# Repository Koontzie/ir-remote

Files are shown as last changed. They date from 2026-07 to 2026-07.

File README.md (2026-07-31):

# IR-Remote

**A three-button universal IR remote you program from your phone** — an ESP32-S3
blasts the infrared code, and a web page (no app store, no build step) tells it
which code to blast over Bluetooth.

<p align="center">
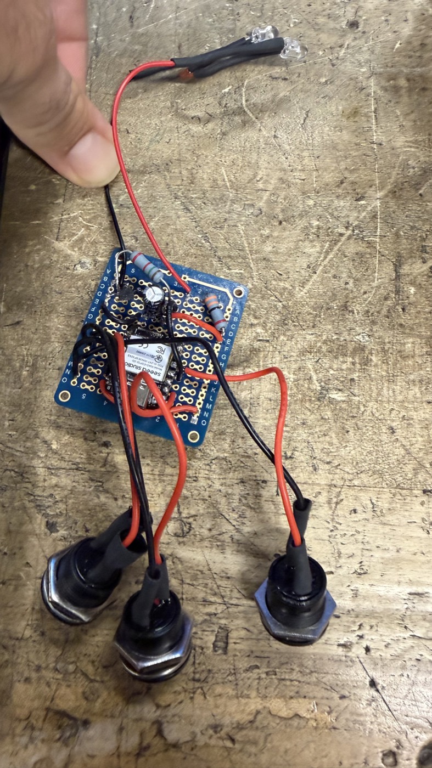
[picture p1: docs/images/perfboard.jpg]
The perf-board build: an ESP32-S3 on protoboard with a transistor IR driver, two IR LEDs on a flying lead, and three panel-mount arcade buttons.
  
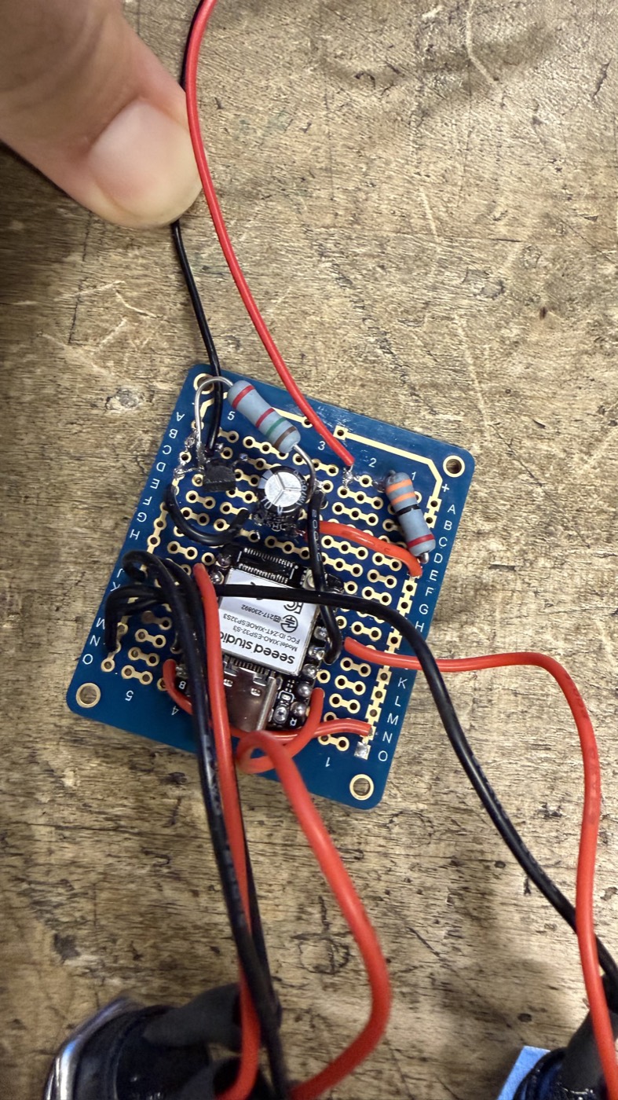
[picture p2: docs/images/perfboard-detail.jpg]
Close-up of the board: Seeed XIAO ESP32-S3, 2N2222 driver, 33-ohm and 1k resistors, and a 470uF bulk cap across the rails.
  
</p>

The point is the last-mile problem in AV work: you're standing in front of an
unlabelled projector or a hotel TV with no remote, and you need power and input
switching *now*. This is a Flipper Zero's universal-remote trick, on $10 of parts,
in a form factor with real buttons you can hit without looking.

## Try it

**→ [koontzie.github.io/ir-remote/app/](https://koontzie.github.io/ir-remote/app/)**

The app is a single static HTML file with no dependencies and no backend. It talks
to the board with **Web Bluetooth**, which means:

- **Desktop Chrome / Edge / Android Chrome** — works as-is.
- **iOS: you need [Bluefy](https://apps.apple.com/us/app/bluefy-web-ble-browser/id1492822055).**
  Not a preference — **Safari has no Web Bluetooth support at all**, and every iOS
  browser is Safari underneath except the handful that ship their own BLE bridge.
  Bluefy is one of those. Open the link above inside Bluefy.
- **Firefox** — no Web Bluetooth. Won't work.

Without hardware you can still browse the code library; the connect button is the
only thing that needs a board.

## How it works

```
[phone or laptop browser]  ──Web Bluetooth──▶  [ESP32-S3 · BLE GATT]
                                                     │  writes to NVS (flash)
[3 physical buttons] ──GPIO──▶ [firmware] ──▶ [2N2222 ──▶ 2× IR LED] ──▶ device
```

Assign a code to a slot once, and the board **keeps it through a power cycle and
fires it with the browser completely disconnected.** It's a real remote, not a
Bluetooth accessory — the phone is a programming tool, not a dependency.

The code library ships in the repo: **317 brands, ~11,100 codes** across TVs,
projectors, monitors, AV receivers, soundbars, cable boxes, Blu-ray and DVD.
Search a brand, pick a function, assign it to a button. Codes shared across many
models of a brand are flagged as "blanket" codes and floated to the top, because
those are the ones most likely to just work.

**GATT interface** (device name `IR-Remote`):

| Role | UUID | Payload |
|---|---|---|
| service | `b457c32b-22b1-425f-8a88-4d6dc37ba4eb` | — |
| `config` (write) | `d997012d-7d2b-47de-ae87-bae14df446ef` | `{"slot":1,"proto":"SAMSUNG","code":"0xE0E040BF","bits":32}` |
| `trigger` (write) | `58397514-04a3-4265-9590-9d910c4e99d2` | `{"slot":1}` |
| `status` (notify) | `b8ddfe01-519f-430d-bd4e-aba0dd852e2c` | `saved:N` / `sent:N` / `pressed:N` / `err:…` |

Five slots (1–5); protocols NEC, SAMSUNG, SONY.

⚠️ **The GATT server is unauthenticated** — anyone in Bluetooth range can write a
config or trigger a slot. That's fine for bench use and it's a deliberate
trade-off, not an oversight; NimBLE bonding would close it if this ever left the
workbench.

## Where it stands

**It works.** The core is built and proven on the bench: IR transmit across a room
(20–30 ft), programming over Bluetooth from the app, codes persisting in flash
through a power cycle, all three physical buttons, and the searchable code library
end to end — pick a Samsung power code in the browser, assign it to a button, and
the TV across the room turns off.

It's a finished thing that does its job. What follows is the honest edge of it,
not a to-do list I'm apologising for.

- **USB-powered.** The circuit runs off the dev board's 5 V pin, so it needs a
  cable or a USB battery pack. A battery-and-deep-sleep version was started and
  stopped after it cost a dev board — see the postmortem below.
- **Identify mode is written but unproven.** Sweeping power codes until the device
  reacts, plus favourites, is implemented in the app and firmware but has never
  been run against real hardware.
- **The custom PCB is designed, not fabricated.** `hardware/` has a complete
  KiCad project, placed and partly routed. Nothing has been sent to a fab, so
  nothing about it is proven.
- **Bluetooth link drops occasionally** (`reason 520`, supervision timeout).
  Annoying, not dangerous — the stored codes and the IR output were verified
  correct either side of every drop.

The unit in the photos is currently dead, and it's a good story rather than a sad
one: during the battery experiment a cheap boost converter's solder-blob voltage
selector let go, silently jumped to 9 V, and cooked the dev board's regulator. The
design was never at fault, a socketed dev board makes it a two-minute swap, and
the full postmortem — along with every other fault this project hit — is in
[docs/DEVLOG.md](docs/DEVLOG.md).

## What's next

No timeline and no promises — the project does what it was built to do. If I pick
it back up:

- **An enclosure.** It's loose boards and panel-mount buttons right now. This is
  the one thing that would turn it from a working circuit into something you'd
  actually carry to a job.
- **Prove out identify mode** on a fresh dev board — the sweep is the feature that
  makes it genuinely universal rather than a nice code browser.
- **Polish the app UI.** It's functional and fast, but it's plainly a tool built
  by one person for one person.

## Bill of materials

| Qty | Part | Notes |
|---|---|---|
| 1 | **Seeed Studio XIAO ESP32-S3** dev board | Any ESP32-S3 dev board works; this is what's pictured. **Socket it** — dev boards die, and a socket makes that a pull instead of a desolder. |
| 2 | IR LED, 940 nm | Wired in series. Salvaged from a dead remote here. Verify a salvaged emitter is actually IR — it glows violet-white on a phone camera. |
| 1 | 2N2222 NPN transistor, TO-92 | Any general-purpose NPN with ≥150 mA collector current. |
| 1 | 33 Ω resistor | LED current limit — sets the ~100 mA pulse. |
| 1 | 1 kΩ resistor | Transistor base. |
| 1 | 470 µF electrolytic capacitor | Bulk decoupling across the 5 V rail. Steadies the rail during LED pulses. |
| 3 | R13-507 16 mm momentary buttons | Panel-mount, solder lugs, no polarity. Any momentary SPST works. |
| 1 | Protoboard + hookup wire | |

Roughly $10–15 if you're buying everything, less if you're raiding a parts bin.

## Wiring

Full card with health checks and measured values: **[hardware/WIRING.md](hardware/WIRING.md)**.

```
POWER
  Dev board 5V pin ──► 5V rail
  Dev board GND    ──► GND rail
  470µF cap across the rails: (+) → 5V, (−) stripe → GND, near the driver.

IR DRIVER (2N2222, TO-92)
  5V rail ──33Ω──► LED1 anode(+)
  LED1(−) ──► LED2(+)                 [series pair, both 940nm]
  LED2(−) ──► COLLECTOR
  EMITTER ──► GND rail
  GPIO4 ──1kΩ──► BASE (middle leg)

BUTTONS (INPUT_PULLUP, pressed = LOW)
  GPIO5 ──► button ──► GND   → slot 1
  GPIO2 ──► button ──► GND   → slot 2
  GPIO7 ──► button ──► GND   → slot 3
```

Two things that cost real bench time here, so they're worth repeating:

- **Meter the transistor's legs; don't assume them.** E/C order varies by vendor
  for the same part number. In diode mode with the red probe on Base, the outer
  leg with the *higher* forward drop is the Emitter.
- **A resistor being present on the board is not the same as it being in the
  current path.** The 33 Ω must be in series with the LEDs, not in the cap's
  branch. Check continuity to the right *node*.

## Build and flash

Toolchain (macOS, Homebrew) — these exact versions are what's verified:

| | Version |
|---|---|
| `arduino-cli` | 1.5.1 |
| `esp32` core | 3.3.10 |
| IRremoteESP8266 | 2.9.0 |
| NimBLE-Arduino | 2.5.0 |
| ArduinoJson | 7.4.3 |

```sh
arduino-cli core install esp32:esp32
arduino-cli lib install IRremoteESP8266 NimBLE-Arduino ArduinoJson

arduino-cli board list      # the port number is NOT stable across replugs
arduino-cli compile --fqbn esp32:esp32:esp32s3:CDCOnBoot=cdc firmware/remote_ble
arduino-cli upload -p <PORT> --fqbn esp32:esp32:esp32s3:CDCOnBoot=cdc firmware/remote_ble

sleep 20 | arduino-cli monitor -p <PORT> -c baudrate=115200
```

`CDCOnBoot=cdc` is required — the S3 talks over native USB CDC, and serial stays
silent without it. `arduino-cli monitor` exits instantly if stdin is closed, hence
the `sleep 20 |` when scripting it.

`firmware/phase1_ir_test/` is a deliberately minimal known-good IR sketch — it
sends one hard-coded Samsung code every 3 seconds. When something stops working,
flash that first to prove the LED path before suspecting anything else.

### Running the app locally

```sh
cd app && python3 -m http.server 8000
```

Open `http://localhost:8000` in desktop Chrome. `localhost` counts as a secure
context, so Web Bluetooth works without HTTPS.

## Repository layout

| Path | What |
|---|---|
| `firmware/remote_ble/` | The real firmware — BLE GATT + IR + 5 NVS-backed slots |
| `firmware/phase1_ir_test/` | Minimal known-good IR sketch, kept as a bisect tool |
| `app/index.html` | The whole app. One file, vanilla JS, no build step |
| `data/` | Generated IR code database — see [data/README.md](data/README.md) |
| `tools/flipper_ir_convert.py` | Flipper `.ir` → IRremoteESP8266 JSON converter + scraper |
| `hardware/` | KiCad 10 PCB project (unfabricated) + the wiring card |
| `docs/` | Design docs and the development log |
| `PLAN.md` | The plan |
| `docs/DEVLOG.md` | A running log of what actually happened — including the failures, in detail |

### Docs

[Code library + Identify mode design](docs/DESIGN-code-library.md) ·
[PCB design](hardware/DESIGN-pcb.md) ·
[hardware working notes](hardware/README.md) ·
[the IR database](data/README.md)

`docs/DEVLOG.md` is worth a look if you're building one of these. It's a blow-by-blow
of every fault hit along the way and how each was actually diagnosed — a dev board
bricked by a boost converter that silently drifted to 9 V, a transistor installed
E/C-reversed, a BLE advertisement overflowing 31 bytes so the device name was
silently dropped, and a board stuck in ROM download mode that looked exactly like
dead firmware. Each entry ends with the lesson rather than just the fix.

## Credits / data sources

The IR code database is built from
**[Lucaslhm/Flipper-IRDB](https://github.com/Lucaslhm/Flipper-IRDB)**, released
under **[CC0-1.0](https://creativecommons.org/publicdomain/zero/1.0/)** — a public
domain dedication that asks nothing of anyone reusing it. It's credited here
anyway, because a community-maintained database of 300+ brands is a real piece of
work and saying so is good manners. See [data/README.md](data/README.md) for how
it's converted and regenerated.

The firmware stands on
[IRremoteESP8266](https://github.com/crankyoldgit/IRremoteESP8266) (despite the
name, first-class ESP32 support) and
[NimBLE-Arduino](https://github.com/h2zero/NimBLE-Arduino).

> **A note on history:** until 2026-07-31 this repo also contained two universal
> code lists taken from
> [DarkFlippers/unleashed-firmware](https://github.com/DarkFlippers/unleashed-firmware),
> which is **GPL-3.0**. Those files and everything derived from them were removed
> when the project adopted the MIT license, and the sweep lists were rebuilt from
> the CC0 database instead. **They are still present in earlier commits** — git
> history was not rewritten. Nothing in the current tree derives from them.

## License

[MIT](LICENSE) © 2026 Tyler Koontz.

## Support

If you found this useful, you can [buy me a coffee](https://ko-fi.com/tylerxkoontz).

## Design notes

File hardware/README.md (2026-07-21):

# hardware/ — BLE IR remote PCB

KiCad 10 project for the custom board. Design decisions and rationale live in
[DESIGN-pcb.md](DESIGN-pcb.md); this file is the how-to-work-on-it notes.

**Nothing here has been fabricated. Nothing is proven.**

| File | What it is |
|---|---|
| `ir-remote.kicad_sch` | Schematic — flat sheet, zoned power / MCU / USB / IR / inputs |
| `ir-remote.kicad_pcb` | Board — 2-layer, 30 × 58mm |
| `ir-remote.kicad_pro` | Project + net classes (POWER_IR, POWER_3V3, USB_DIFF) |
| `DESIGN-pcb.md` | Pin map, power tree, BOM, sleep budget, decisions |

---

## ⚠️ KiCad 10 net format — do not "repair" it

KiCad 10 (board format `20260206`) references nets **by name**:

```
(net "GND")        <- pads, tracks and vias, KiCad 10
(net 2 "GND")      <- KiCad <= 9 pads; the numeric index and the top-level
                      (net N "name") table no longer exist
```

`kicad-cli --save-board` — KiCad's own serialiser — writes the name-only form,
and DRC resolves it correctly (`Pad 5 [BTN1]`, `Track [BTN1]`). The kicad-mcp
writer produces the same thing, correctly.

**This tripped me once.** `grep '(net [0-9]'` returns zero on a perfectly healthy
KiCad 10 board, which looks alarming. I concluded the MCP was corrupting the
file and wrote a script to add the old index table back. It "worked" only
because KiCad still parses the legacy form — the board was never broken, and the
script eventually introduced a genuine inconsistency of its own. Deleted.

**Check what this KiCad version actually writes before concluding a tool is
broken:**

```sh
kicad-cli pcb drc --output /tmp/drc.rpt ir-remote.kicad_pcb
grep -A3 unconnected /tmp/drc.rpt     # healthy: nets show as [GND], [BTN1], ...
```

## Real MCP traps that do apply

- **External edits block the next auto-save.** Touch the `.kicad_pcb` outside the
  MCP and its next save is *refused* (mtime guard, `diskChangedExternally`);
  your changes then exist only in server memory until they're lost. Call
  `open_project` to re-sync first.
- **`assign_net_to_class` and `add_net_class` are advertised but not
  implemented** — they return `Unknown command`. Net-class assignment has to be
  written into `ir-remote.kicad_pro` (`net_settings.netclass_patterns`) directly.
- **`refill_zones` has a documented segfault risk** on the swig backend. Use
  `kicad-cli pcb drc --refill-zones --save-board` instead — it fills zones
  natively and safely.
- **ERC violation coordinates from the MCP are in unusable normalised units.**
  Use `kicad-cli sch erc` for a readable report.

---

## Verification commands

```sh
# ERC
kicad-cli sch erc --output erc.rpt --severity-all ir-remote.kicad_sch

# DRC, refilling zones first (DRC on unfilled pours is meaningless)
kicad-cli pcb drc --refill-zones --save-board --output drc.rpt --severity-error ir-remote.kicad_pcb

# 3D renders
kicad-cli pcb render --output layout-top.png    --side top    ir-remote.kicad_pcb
kicad-cli pcb render --output layout-bottom.png --side bottom ir-remote.kicad_pcb
```

## Autorouting

Freerouting, not the MCP's `autoroute` (it probes `/usr/bin/java`, the macOS
stub, and will not find a Homebrew JDK).

- **Freerouting 2.2.x needs Java 25** (class file v69). **Use 2.1.0** — class
  file v65, runs on Java 21.
- Java: `/opt/homebrew/opt/openjdk@21/bin/java` (keg-only, not on PATH).

```sh
java -Djava.awt.headless=true -jar ~/.kicad-mcp/freerouting.jar \
     -de ir-remote.dsn -do ir-remote.ses -mp 50 -dct 0
```

**The MCP DSN export drops net classes** — everything comes out at 0.2mm,
including the 220mA IR paths. The DSN must be patched to add `POWER_IR` (600µm),
`POWER_3V3` (500µm) and `USB_DIFF` (250µm) classes before routing.

## Fab notes (JLCPCB, 2-layer)

| Parameter | Value |
|---|---|
| Size | 30 × 58mm, 2mm corner radius |
| Layers / thickness | 2 / 1.6mm |
| Surface finish | HASL (lead-free fine) |
| Min track / clearance | 0.127mm / 0.2mm |
| Min drill | 0.3mm |
| Copper | 1oz |

**Watch item:** the stock KiCad `ESP32-S3-WROOM-1` footprint ships 12 thermal
vias at **0.2mm drill**, under JLCPCB's 0.3mm minimum. They are enlarged to
0.3mm in this board. If the footprint is ever re-imported from the library,
that fix is lost — re-check before ordering.

## Antenna keepout — do not "optimise" this away

The ESP32-S3-WROOM-1 footprint declares a large antenna clearance area
(x < 7.75mm for the full board height in the current orientation). No copper,
no pour, no components, no stitching vias in it. The ground pours are cut back
to respect it, which is why the left strip of the board looks empty.

The MCP's `add_gnd_stitching_vias` works off the **board outline, not the pour
outline**, and will happily place vias straight through the keepout. Use the
`in_zones` strategy or place them by hand.

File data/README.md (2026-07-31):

# `data/` — the IR code database

Everything in this directory is generated by
[`tools/flipper_ir_convert.py`](../tools/flipper_ir_convert.py) from
[**Lucaslhm/Flipper-IRDB**](https://github.com/Lucaslhm/Flipper-IRDB), which is
released under **CC0-1.0** (public domain dedication). Nothing here is
hand-written, and nothing here comes from any other source — see
[Provenance](#provenance) below for why that matters.

## Layout

| Path | What it is |
|---|---|
| `db/index.json` | Categories → brands → shard path + per-function counts. The app loads this at startup. |
| `db/search.json` | One compact record per brand (brand, category, canonical functions, model strings). ~61 KB — powers the search box without fetching any shards. |
| `db/<category>/<brand>.json` | One shard per brand, lazy-loaded when you open that brand. |
| `db/unmapped-names.txt` | Button names the canonicaliser did **not** recognise, with occurrence counts. A worklist, not an error log. |
| `sweep-tv.json`, `sweep-projector.json` | Ordered power-code lists for Identify mode's sweep. |

Totals: **8 categories, 317 brands, ~11.1K sendable codes** (plus ~2.6K RAW
timing arrays that the firmware can't send yet).

## Code entries

Each shard is a flat array. A representative entry:

```json
{"name":"power_toggle","orig":"Power","brand":"Samsung","model":"Samsung",
 "proto":"SAMSUNG","code":"0xE0E040BF","bits":32,"nmodels":36,"generic":true}
```

| Field | Meaning |
|---|---|
| `name` | Canonical function (`power_on`, `input_hdmi1`, `vol_up`, …). Anything the canonicaliser wasn't confident about becomes `other:<original>` — it guesses at nothing. |
| `orig` | The original IRDB button name, always preserved. |
| `model` | The `.ir` filename the code came from. |
| `proto` / `code` / `bits` | Ready for IRremoteESP8266. `proto` is `RAW` for timing arrays, which carry `freq` + `data` instead of `code`. |
| `nmodels` | How many distinct models in this brand share this exact code. Absent means one. |
| `generic` | Set when `nmodels >= 3` — a brand-wide "blanket" code, the universal-remote sweet spot. The app floats these to the top of a brand's list. |

**The conversion is not a copy.** Flipper stores address/command bytes LSB-first;
IRremoteESP8266 wants an MSB-first assembled frame. Each byte is bit-reversed and
the frame built per protocol (NEC: `addr,~addr,cmd,~cmd`; Samsung32:
`addr,addr,cmd,~cmd`; NECext: `addr16,cmd,~cmd`; SIRC: `addr<<7|cmd`). That math
is bench-validated — it reproduces `SAMSUNG 0xE0E040BF`, the code physically
verified against the test TV.

## Sweep lists

Identify mode fires power codes one at a time until the device reacts, so the
order is the whole game. `build_sweep_from_db()` builds each list by:

1. Taking every non-RAW power code from the relevant categories (`tv` draws from
   `tvs` + `monitors`, since the app maps monitors onto the TV list; `projector`
   from `projectors`).
2. Summing each code's **model spread** across every brand — the same signal
   behind the `generic` flag, widened from one brand to a whole category.
3. Deduping by `(proto, code)`, keeping the canonical reading with the most
   models behind it.
4. Sorting `power_on` → `power_toggle` → `power_off`, and **spread-descending
   within each group**.

The group order outranks hit rate on purpose: a discrete `power_on` can't turn
off a device that's already on, so it's safe to try first, while a toggle sent at
a device that's already awake looks exactly like a miss.

Current sizes: **70 TV codes** (~28s at 400 ms/code) and **57 projector codes**
(~23s). The widest-spread entries are LG `NEC 0x20DF10EF` (57 models), Samsung
`0xE0E040BF` (39) and Sony `0x95` (27).

## Regenerating

```sh
git clone --depth 1 https://github.com/Lucaslhm/Flipper-IRDB.git /tmp/Flipper-IRDB
python3 tools/flipper_ir_convert.py --scrape /tmp/Flipper-IRDB --out data/db
```

Clone to a temp directory, **not** into this repo. The run rewrites `db/` and
both sweep lists, then checks four sanity gates and exits non-zero if any fail:

- the bench-verified `SAMSUNG 0xE0E040BF` is present in the Samsung TV shard
- the NEC projector shard has discrete `power_on` *and* `power_off`
- blanket-code promotion actually fired for Samsung TVs
- `search.json` exists and indexes Samsung TVs

The scrape is deterministic — re-running against the same upstream commit
produces byte-identical output, so a non-empty `git diff` on `data/db/` means
upstream genuinely changed.

## Provenance

The database is **CC0-1.0** throughout, which imposes no conditions on reuse.
It is credited anyway, in the README and here, because that's good manners.

Until 2026-07-31 the two sweep lists were built from a different source, and the
full record of what that was matters more than the fact it's gone:

`data/source/tv.ir` (613 entries, 295 power codes) and
`data/source/projectors.ir` (302 entries, 138 power codes) were the universal IR
library assets shipped with the Flipper Zero **Unleashed** firmware, taken from
`applications/main/infrared/resources/infrared/assets/` in
[DarkFlippers/unleashed-firmware](https://github.com/DarkFlippers/unleashed-firmware).
Their file headers date them 2024-10-05; they were fetched for this project on
2026-07-19. Those assets in turn build on the
[official Flipper Zero firmware](https://github.com/flipperdevices/flipperzero-firmware)
(also GPL-3.0) and on community submissions to Flipper-IRDB (CC0-1.0).
`data/tv.json` and `data/projectors.json` were machine conversions of them, and
therefore derived works carrying the same terms.

**Unleashed is GPL-3.0**, which is copyleft: anything redistributing those assets
has to be GPL-3.0-compatible, and MIT is not. So when this project took an MIT
license, the two `.ir` files, both converted `.json` outputs, and the converter
code path that read them were removed, and the sweep lists were rebuilt from the
CC0 database instead — the option the original attribution note had already
identified as the way out of the constraint.

⚠️ **The removed files remain in this repository's git history**; history was not
rewritten. That's deliberate — deleting going forward is proportionate, and
force-pushing would break every existing clone to no real benefit. Nothing in the
current tree derives from them.

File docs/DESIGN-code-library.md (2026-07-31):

# Design — Code Library + Identify Mode (Phase 5)

**Why:** This project targets projectors and monitors from many brands
(Samsung, LG, NEC, +more), often unlabeled or unreachable. Today that means
digging through menus and trying every brand. This phase gives the remote a
built-in code library with dropdowns, and an **Identify mode** that sweeps
power codes across all brands until the device reacts — the Flipper Zero
universal-remote trick, on our hardware.

## Data sources (fetched 2026-07-19, in repo)

> ⛔ **Superseded 2026-07-31 — the files in this table are gone.** They came from
> `DarkFlippers/unleashed-firmware`, which is **GPL-3.0**; the project is now
> licensed MIT, so they and everything derived from them were removed. The sweep
> lists are rebuilt from the CC0 `data/db/` instead (see
> `build_sweep_from_db` in `tools/flipper_ir_convert.py` and `data/README.md`).
> The table is kept for the record; do not try to restore these files.

| File | Entries | What |
|---|---|---|
| ~~`data/source/tv.ir`~~ | 613 (295 power) | Flipper Unleashed universal TV list — **removed, GPL-3.0** |
| ~~`data/source/projectors.ir`~~ | 302 (138 power) | Flipper Unleashed universal projector list — **removed, GPL-3.0** |
| ~~`data/tv.json`, `data/projectors.json`~~ | converted | derived from the above — **removed** |
| `data/db/**` | ~13.8K codes | `Lucaslhm/Flipper-IRDB` (**CC0-1.0**) — the only source now |

- Converter: `tools/flipper_ir_convert.py`. Flipper stores LSB-first bytes;
  IRremoteESP8266 wants MSB-first codes — each byte is bit-reversed, then
  frames assembled per protocol (NEC: addr,~addr,cmd,~cmd; Samsung32:
  addr,addr,cmd,~cmd; NECext: addr16,cmd,~cmd; SIRC: addr<<7|cmd).
- **Validated:** converter reproduces `0xE0E040BF` (SAMSUNG power) from
  Flipper's entry — the exact code physically verified on the bench TV. ✅
- Protocol coverage: NEC+NECext+Samsung32 ≈ 85% of parsed entries; SONY(SIRC),
  RC5, RC6 converted but **unverified against hardware**; Kaseikyo/RCA/
  Pioneer/NEC42/RC5X marked TODO (23 entries); ~26% of entries are RAW timing
  arrays (many projectors!) — see BLE note below.
- **Brand-attributed browsing DB** (pick brand → device → function) comes from
  Flipper-IRDB proper (`Lucaslhm/Flipper-IRDB`). **Decision 2026-07-19: scrape
  the full AV-relevant library, not a brand subset** — measured sizes make it
  trivial: Projectors 1.4MB/126 files/54 brands, TVs 2.6MB/397 files, Monitors
  64KB, plus AV Receivers, SoundBars, Cable Boxes, Blu-Ray, DVD ≈ **<10MB of
  source text total** (skip `_Converted_`, 85MB of other-ecosystem exports; skip
  ACs — stateful protocols, different beast; skip Toys/Fans/LEDs etc.).
  Output: one JSON shard per brand (`data/db/projectors/nec.json`), plus a
  small `data/db/index.json` (categories → brands → file, counts). App fetches
  the index at load and brand shards on demand — Pages serves it all statically.
- **Universal lists have NO input/source codes** (verified: power/vol/mute only).
  The two functions Tyler's AV work needs most are **power on/off and input
  switching** — so the brand-DB scrape must extract: `Power`, discrete
  `Power_on`/`Power_off`, `Source`/`Input`, discrete `HDMI1/2/...`,
  `VGA`/`Comp`, plus vol/mute as gravy. Index the scraped DB by
  (protocol, address) to power the keymap-unlock step below.

## Feature 1 — Library dropdowns in the app

Replace/augment the raw hex form: Device type → Brand → Function dropdowns,
filled from `data/*.json` (static fetch, same GitHub Pages origin). Selecting a
function fills protocol/code/bits; Save-to-slot and Test work as today. Custom
hex entry stays for codes not in the DB.

## Feature 2 — Identify mode (the brand-hunt killer)

**UX (app-driven, phone connected):**
1. Pick device type (Projector / TV / Monitor) → optional brand guess to try
   that brand's codes first.
2. Aim remote. Hit **START**. App streams power codes over BLE one at a time,
   ~400ms apart (~100ms IR transmit + gap), progress bar + current index shown.
3. Device reacts → user hits **STOP**. **Keep the FULL sent history for the
   run, not a last-5 window.** Tyler's real workflow: the win condition is
   usually "it powered on and showed a splash screen," and projector warmup
   means visible feedback can lag the winning code by **5–30 seconds** —
   15+ codes at sweep speed. A short window would routinely miss it.
   After STOP the app shows the ordered history (newest first) with each entry
   re-sendable, plus a **bisect helper**: because the device is now ON and
   *stays* on, the user can power it off and replay a *subset* of the history
   to halve the candidate range each round. ~5 rounds pinpoints one code out
   of 50. Persistent state is what makes bisecting possible — lean on it.
   Also expose an adjustable sweep interval (default ~400ms; slower for
   sluggish gear) and a **manual step mode** (tap to send the next code) for
   when the user would rather go one at a time than sweep and backtrack.
4. "It's this one" → name it, save to a slot, and (later) log it to a site
   inventory list.
5. **Keymap unlock:** all functions on one remote share the protocol + address;
   only the command byte differs. On a hit, the app searches the brand DB for
   entries with the same (protocol, address) and surfaces that device's full
   keymap — Source/Input/HDMI, discrete power, volume — as one-tap test
   buttons. Inputs are never swept for; they're unlocked by the power hit.
   (Device is now on, so input changes give visible confirmation.)

Sweep sizing from real data: projectors = 51 deduped parsed power codes
(~20s sweep); TVs = 130 (~52s). RAW entries add 34/156 more once chunked
writes exist. Sweep list ships as a dedicated `data/sweep-{type}.json`,
deduped by (proto,code), NEC-family first (highest hit rate).

**Firmware additions:**
- New protocols in the send switch: SONY, RC5, RC6 (IRremoteESP8266 has them
  all natively — small map extension).
- `trigger` accepts direct send `{"proto":"NEC","code":"0x...","bits":32}`
  (no slot round-trip) — the sweep uses this; slots stay for the buttons.
- Status notify per send keeps app and firmware in lockstep during sweeps.

**BLE payload wrinkle (RAW codes):** raw timing arrays are 100–250 uint16s =
up to ~1KB, far over the 23-byte default ATT MTU. NimBLE negotiates up to 517;
Web Bluetooth writes cap at 512 bytes. Plan: request MTU 517 + chunked
`config`-style transfer (seq-numbered fragments, reassemble in firmware).
Defer RAW to a second pass — parsed codes alone give 51 projector +
130 TV codes, which is already better than the menu-diving status quo.

**Discrete ON/OFF (AV gold):** many projectors (esp. NEC protocol families)
have *discrete* power-on and power-off codes, not just toggle. When the
brand DB lands, surface these distinctly — "shut down every projector in the
room without toggling the off ones back on" is a real workflow win.

## Feature 3 — Favorites (Tyler's work fleet)

The library is the ocean; Favorites is the toolbox. A named list of the codes
Tyler actually uses at work, built up as he goes:

- **Add from anywhere:** an Identify hit, a library browse, or the keymap-unlock
  view — every code row gets a ☆. Favorites are named by the user
  ("Shop 3 NEC proj — HDMI2"), optionally grouped by site/room.
- **Front and center:** favorites render as big tap-pads at the top of the app,
  above the slot editor — the daily-driver screen. Library browsing is the
  occasional path.
- **Storage:** `localStorage` (persists in Bluefy and Chrome independently) +
  one-tap **export/import as JSON** (share codes between phone and desktop, back
  up, or hand a coworker your entire site kit as a text file). Keep the format
  human-readable.
- Slots (the 5 physical-button bindings) are unchanged — a favorite can be
  pushed to a slot, which is how a work device ends up on a hardware button.

## Standalone sweep (later, pairs with Phase 4)

Long-press button 2 = sweep projector power list from flash (LittleFS or
PROGMEM, no phone needed); short-press again = stop. Requires the sweep list
baked into firmware at build time. Deferred until battery/deep-sleep phase
settles the power/wake architecture.

## Field-use feedback (Tyler, 2026-07)

Three changes that came out of actually holding the thing:

1. **Search, not browse.** Full brand/model dropdowns are too much to wade
   through on a ladder. Primary UI should be a single search box —
   type "epson", "ne", "hdmi" and get matching entries live, fuzzy across
   brand + model + function name. Dropdowns become the fallback, not the front
   door. Search index built at scrape time (small JSON, brand+model+function
   strings only; shards still lazy-load on selection).

2. **Discrete power-on beats toggle — surface it first.** In AV work, toggle
   is actively dangerous: hit a room of projectors with toggle and you turn
   half of them off. Where a brand DB entry has discrete `power_on` /
   `power_off`, present those as the default action and mark toggle as the
   fallback ("toggle only — no discrete code known"). Sweep/Identify should
   also prefer power_on codes where they exist, since a device that's already
   on stays on rather than flickering off.

3. **Generic/blanket codes.** Many brands share a protocol+address family
   (a "Samsung TV" code often works across dozens of models). At scrape time,
   detect codes that repeat across many models within a brand and promote them
   to a per-brand "generic" entry (e.g. "Samsung TV — generic power_on"), shown
   at the top of that brand's list. That collapses hundreds of near-duplicate
   model entries into a handful of high-hit-rate picks — closer to how a
   universal remote actually gets used.

4. **Show the code that was sent.** When a physical button fires, the app's
   status area should display what went out — slot, protocol, code, and the
   friendly name if the code came from the library ("Samsung TV — power_on
   0xE0E040BF"). Confirmed useful in the field: you learn what a button is
   without opening its config.

## Open items

- [ ] Tyler: brand/device list from work → scopes the Flipper-IRDB scrape.
- [ ] Verify RC5/RC6/SIRC conversions against a real Philips/Sony device.
- [ ] RAW chunked-write protocol (unlocks 190 more codes incl. many projectors).
- [ ] Site inventory: identified devices → named entries (JSON export?).

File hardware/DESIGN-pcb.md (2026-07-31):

# DESIGN — Custom PCB (BLE IR remote)

**Status:** GATE 2 PASSED 2026-07-21 — decisions below are final. Schematic in progress.
**Created:** 2026-07-21 · Originating brief `docs/CC-BRIEF-pcb.md`, removed
2026-07-31; it survives in git history at commit `377163c`.
**Target:** 2-layer, **30 × 58mm**, hand-solderable (0603 min), ESP32-S3-WROOM-1-N8.

> ### ⚠️ Approved deviation from the brief: 30 × 58mm, not ≤ 30 × 50mm
> Approved at Gate 3, 2026-07-21. **Reason: the antenna keepout is
> non-negotiable.** The ESP32-S3-WROOM-1 footprint declares 15 keepout rule
> areas around its antenna, and Espressif's layout guide requires that clearance
> for the radio to work at all. At 30 × 50mm, DRC put R13, SW1, SW4 and SW6
> *inside* those keepout areas, with 15 further courtyard overlaps between the
> button block and the module — 36 violations that were all one symptom: the
> outline was too small for the module + 7 buttons + 2 THT IR LEDs + USB-C +
> JST. Nudging parts could not fix it.
> +8mm on the long axis buys ~4mm between the buttons and the module and clears
> every part out of the antenna zone. The board is still pocketable and still
> sized for the 503035 cell. **Shrinking the board would mean degrading the
> antenna — that trade was refused.**

**Product constraint: BLE only. WiFi is permanently disabled in firmware.**
Not merely unused — never initialised. This is what lets a 500mA LDO carry the
MCU with margin (WiFi TX peaks ~355mA; BLE TX peaks ~130mA) and it keeps ADC2
off the table permanently, which is why VBAT_SENSE lives on ADC1 (§2).

Everything here is a paper design. **No claim in this document has been
validated on hardware.** Current figures are datasheet-typical and flagged
where I have not personally confirmed them against a datasheet PDF.

---

## 1. Decisions taken at Gate 2

### 1.1 LDO: HT7833 (SOT-89) — replaces the briefed AP2112K

The brief specified both `AP2112K-3.3 (~55µA IQ)` and `deep-sleep budget < 20µA`.
**The regulator alone was ~3× the entire budget** — the two could not both hold.
Tyler's call: **HT7833**, 500mA, SOT-89.

| LDO | IQ (typ) | Iout | Pkg | Sleep total |
|---|---|---|---|---|
| AP2112K-3.3 (as briefed) | ~55µA | 600mA | SOT-23-5 | ~65µA ✗ |
| **HT7833 (chosen)** | **4µA** | **500mA** | **SOT-89** | **~14.5µA ✓** |

500mA of headroom keeps the BLE TX peak (~130mA) comfortable, and SOT-89 is a
larger, easier hand-solder package than SOT-23 with far better thermals
(θJA 200°C/W vs 500°C/W).

#### ⚠️ Pinout: web sources are wrong about this part — verify against the PDF

Two independent web searches both reported HT7833 SOT-89 as **pin2=VOUT,
pin3=VIN**, and both claimed an input range of **"4.5V to 8V"** (which would have
disqualified the part for a 3.0–4.2V LiPo outright). **Both claims are false.**

Confirmed against the Holtek HT78xx series datasheet **Rev. 1.50, 2019-04-03**,
Pin Description table:

| SOT-89 pin | Name | | Spec | Datasheet value |
|---|---|---|---|---|
| **1** | **GND** | | VIN max | 8V (abs max supply 8.5V) |
| **2** | **VIN** | | VIN min | **none specified** — LiPo range is fine |
| **3** | **VOUT** | | IQ (IO=0mA) | 4µA typ / **7µA max** |
| — | *(no CE pin in SOT-89)* | | Dropout @3.3V | 500mV typ / 650mV max **at 500mA** |
| | | | Current limit | 500mA min |

Because the real pinout is GND/VIN/VOUT, the stdlib symbol
**`Regulator_Linear:HT75xx-1-SOT89`** (same Holtek TinyPower family, identical
package and pin order) is an exact match. **No generic symbol or hand-made part
is needed** — the Gate 2 fallback plan turned out to be unnecessary.

Dropout is specified at 500mA; we never draw that. At the ~130mA BLE peak expect
~130mV, so the 3V3 rail holds regulation down to VBAT ≈ 3.45V. Below that the
rail sags with the cell instead of regulating — benign, since the ESP32-S3 runs
to 3.0V and a 1S LiPo at 3.45V is nearly empty.

### 1.2 Charge rate: R_PROG = 4.7kΩ (212mA), cell 400–500mAh

The brief said "500mA program resistor" while also allowing a 250mAh cell — that
combination is 2C, a fire risk, not just a wear issue. Resolved by fixing the
cell size instead of the resistor.

**Cell: 503035-class LiPo, 400–500mAh, ~30 × 35 × 5mm, with integral PCM.**
At 212mA that is **0.42–0.53C** — comfortably in the 0.5C sweet spot. Charge
time ≈ 2h for 400mAh. `I_charge = 1000V / R_PROG` (MCP73831 datasheet).

The 30 × 35mm cell footprint sits under the 30 × 50mm board (§8) with the JST
lead exiting toward the bottom edge.

### 1.3 Gate resistor: 100Ω, not the briefed 1kΩ

The brief says `GPIO4 → 1kΩ → NPN/MOSFET`. 1kΩ is correct for an **NPN base**
(current-driven). I'm proposing **MOSFETs** (see §4), which are voltage-driven —
1kΩ into ~700pF Ciss gives a ~0.7µs edge on a 13µs half-cycle at 38kHz, which
smears the carrier. **100Ω series + 100kΩ pull-down** is the right MOSFET
equivalent. The pull-down is not optional: it holds the gate off while the ESP32
is in reset or deep sleep, otherwise a floating gate can half-turn-on the LED and
quietly eat the battery.

---

## 2. Pin map (FINAL — firmware depends on this)

ESP32-S3-WROOM-1-N8. All button pins are RTC-capable (GPIO 0–21) for EXT1
deep-sleep wake. Strapping pins 0/3/45/46 and USB 19/20 respected.

| Signal | GPIO | Dir | Why this pin |
|---|---|---|---|
| **IR_CH1** (room blast) | **4** | out | Unchanged from Phase 1–3 firmware. RMT-capable. |
| **IR_CH2** (long throw) | **7** | out | Per brief. RMT-capable, RTC, not strapping. |
| **BTN1** | **5** | in, pull-up | Already mapped + proven in firmware. RTC ✓ |
| **BTN2** | **2** | in, pull-up | Already mapped in firmware (GPIO6 was not broken out on the devkit). RTC ✓ |
| **BTN3** | **15** | in, pull-up | RTC ✓, exposed on WROOM-1, free |
| **BTN4** | **16** | in, pull-up | RTC ✓, exposed, free |
| **BTN5** | **17** | in, pull-up | RTC ✓, exposed, free |
| **VBAT_SENSE** | **1** | ADC | **ADC1_CH0 — must be ADC1.** ADC2 is unusable while the radio is on. |
| **BOOT** | **0** | strap | Tactile to GND + 10k pull-up. **Nothing else on this net** (see docs/DEVLOG.md — a stray connection here cost a debugging session). |
| **RESET** | **EN** | — | Tactile to GND + 10k pull-up + 1µF |
| **USB D−** | **19** | — | Native USB only |
| **USB D+** | **20** | — | Native USB only |

Buttons wire `GPIO → switch → GND`, `INPUT_PULLUP`, pressed = LOW — identical to
the breadboard, so Phase 3 firmware moves over with only the BTN3–5 additions.

**Deliberately unused:** 3/45/46 (strapping), 26–37 (flash), 38–48 (no need).

**EXT1 wake mask** = GPIO 2, 5, 15, 16, 17 → `ext1_wakeup(mask, ANY_LOW)`.

---

## 3. Power tree

```
USB-C VBUS (5V) ──┬── USBLC6-2SC6 (ESD: VBUS, D+, D−)
                  │
                  └── MCP73831 VDD ──> VBAT (3.0–4.2V) ──┬── JST-PH ── LiPo 1S
                        R_PROG 4.7k                       │            (protected cell)
                        STAT ── 1k ── LED (charge)        │
                                                          ├── HT7833 (SOT-89) ──> +3V3 ──> ESP32-S3
                                                          │                                (only load)
                                                          ├── 100µF bulk
                                                          │
                                                          ├── 22Ω ── IR LED CH1 ── AO3400A ── GND
                                                          │                          ▲ GPIO4
                                                          ├── 12Ω ── IR LED CH2 ── AO3400A ── GND
                                                          │                          ▲ GPIO7
                                                          └── 2M/2M divider ──> GPIO1 (ADC1)
```

**No 5V rail exists on this board.** VBUS goes to the charger and nowhere else.

**No power-path IC.** The load hangs off the VBAT junction (the Adafruit Feather
arrangement). Known and accepted tradeoff: while charging, load current is
indistinguishable from charge current, so the MCP73831's termination is
imprecise and the cell may top-off cycle. At ~12µA sleep / ~40mA active against
212mA charge this is a non-issue in practice. A diode-OR was rejected — its
0.3V drop would break both charging and the LDO headroom.

**Battery protection is in the cell, not on the board.** Spec a pouch cell with
an integral PCM. There is no on-board over-discharge cutoff.

---

## 4. Bill of materials (with rationale)

| Ref | Part | Pkg | KiCad symbol | Why |
|---|---|---|---|---|
| U1 | ESP32-S3-WROOM-1-N8 | module | `RF_Module:ESP32-S3-WROOM-1` | Matches all existing firmware |
| U2 | **HT7833** | **SOT-89** | `Regulator_Linear:HT75xx-1-SOT89` | §1.1 — 4µA IQ makes <20µA reachable; 500mA + good thermals. **Symbol is a family match, verify pinout GND/VIN/VOUT** |
| U3 | MCP73831-2-OT | SOT-23-5 | `Battery_Management:MCP73831-2-OT` | Your call at Gate 1. Smallest 1S charger with a clean stdlib symbol |
| U4 | USBLC6-2SC6 | SOT-23-6 | `Power_Protection:USBLC6-2SC6` | ESD on D+/D−/VBUS |
| J1 | USB-C recept. USB2 16P | SMD | `Connector:USB_C_Receptacle_USB2.0_16P` | Charge + native USB programming |
| J2 | JST-PH 2-pin | TH | `Connector_Generic:Conn_01x02` | Battery. **Polarity differs by vendor — silkscreen it** |
| Q1,Q2 | **AO3400A** | SOT-23 | `Transistor_FET:AO3400A` | 30mΩ NMOS. Beats an NPN's 0.25V Vce(sat), which matters at VBAT=3.0V |
| D1,D2 | IR LED 940nm | — | `Device:LED` | D1 wide ±60°, D2 narrow ±10–15° (TSAL6100 class) |
| D3 | LED (charge status) | 0603 | `Device:LED` | On VBUS side of STAT — **zero battery drain when unplugged** |
| SW1–5 | Tactile SPST | SMD | `Switch:SW_Push` | `SW_SPST_SKQG_WithStem`, top face |
| SW6,7 | Tactile (BOOT, RESET) | SMD | `Switch:SW_Push` | The unbrick path |
| R1 | 22Ω | 0603 | | CH1 current set, §5 |
| R2 | 12Ω | 0603 | | CH2 current set, §5 |
| R3,R4 | 100Ω | 0603 | | Gate series, §1.3 |
| R5,R6 | 100kΩ | 0603 | | Gate pull-down, §1.3 |
| R7,R8 | 5.1kΩ | 0603 | | CC1/CC2 → GND, UFP device role |
| R9 | 4.7kΩ | 0603 | | R_PROG → 212mA charge, §1.2 |
| R10,R11 | 2MΩ | 0603 | | Battery divider, §6 |
| R12,R13 | 10kΩ | 0603 | | BOOT / EN pull-ups |
| R14 | 1kΩ | 0603 | | Charge LED |
| C1 | 100µF | 1210 | | **VBAT bulk beside the IR drivers** — supplies the 200mA pulses |
| C2 | 22µF | 0805 | | 3V3 bulk (Espressif module requirement) |
| C3 | 10µF | 0603 | | LDO output |
| C4 | 4.7µF | 0603 | | Charger VBAT |
| C5 | 1µF | 0603 | | EN RC reset |
| C6–C9 | 100nF | 0603 | | Decoupling + ADC reservoir (§6) |

All symbols/footprints verified present in the KiCad 10 stdlib at Gate 1.
**Nothing needs SnapEDA or a hand-drawn part.**

---

## 5. IR drive current

`I = (VBAT − Vf − Vds(on)) / R`, with AO3400A Vds ≈ 0.01V at these currents.

| | R | @3.0V (empty) | @3.7V (nominal) | @4.2V (full) |
|---|---|---|---|---|
| **CH1** wide, Vf≈1.35V | 22Ω | 75mA | 107mA | **130mA** |
| **CH2** narrow, Vf≈1.6V | 12Ω | 117mA | **175mA** | 217mA |

Both stay inside a TSAL6100-class 200mA DC / 1.5A pulsed rating, and IR carrier
duty is ~33% within a burst with bursts ~1% of wall time. Range should beat the
breadboard's 20–30ft: that was 64mA through two series LEDs off a 5V rail.

**Deliberate consequence:** brightness sags ~40% as the cell drains, because
these are resistor-set, not constant-current. Accepted — a constant-current sink
costs parts and quiescent draw, and IR range degrades gracefully.

---

## 6. Battery sense

2MΩ / 2MΩ divider → GPIO1 (ADC1_CH0). 4.2V → 2.1V, inside the 12dB-attenuation
range. Costs **1.05µA** continuous.

The ESP32 ADC wants a source impedance far below 1MΩ, so a **100nF reservoir cap
at the tap** is mandatory — it holds charge for the sample window. It stays
charged across deep sleep, so only the very first reading after a cold boot needs
a settling delay (~200ms).

A MOSFET-switched divider would drop this to ~0µA, but 1.05µA out of a 12µA
budget is not worth the part and the extra GPIO.

---

## 7. Deep-sleep current budget

Target < 20µA. **All values datasheet figures, none measured on hardware.**

| Item | Typ | Max | Confidence |
|---|---|---|---|
| ESP32-S3-WROOM-1 deep sleep (RTC mem + EXT1) | 7.0µA | 8µA | Espressif datasheet typ |
| **HT7833 quiescent** | **4.0µA** | **7.0µA** | ✅ Verified, HT78xx Rev 1.50 |
| MCP73831 battery drain, VDD floating | 2.0µA | 2.0µA | **Least certain — verify** |
| Battery-sense divider (2M+2M @ 4.2V) | 1.05µA | 1.05µA | Ohm's law, certain |
| USBLC6-2SC6 leakage | 0.2µA | 1.0µA | Datasheet max 1µA |
| AO3400A ×2, gates held low | 0.2µA | 2.0µA | Idss max 1µA ea; typ is nA |
| Charge LED (unplugged) | 0µA | 0µA | Structural — anode on VBUS |
| **TOTAL** | **≈14.5µA ✓** | **≈21µA ⚠** | |

**Typical passes with ~27% headroom. Worst-case-everything lands ~21µA, a hair
over target** — but that stacks every datasheet maximum simultaneously, which is
not a realistic operating point. Called out rather than hidden.

On a 450mAh cell at 14.5µA: **~3.5 years standby** — self-discharge, not the
circuit, becomes the limit. That is the correct place to land.

Same table with the briefed AP2112K: **65.5µA ✗**.

**The single largest unverified number is the MCP73831's reverse battery drain.**
If it turns out worse than ~2µA it is the one part that could push typical over
budget. Measure it first when boards arrive.

---

## 8. Layout intent (detail deferred to Step 4)

Board 30 × 50mm, 2-layer, 1.6mm, ground pour both sides + stitching vias.

**The one real conflict: the antenna and the USB-C both want a board edge, and
the IR LEDs want the *front* edge.** Proposed resolution:

```
        ┌──── FRONT (points at the TV) ────┐
   30mm │   [D1 wide]      [D2 narrow]     │  IR LEDs, side by side
        │                                  │
        │   SW1  SW2  SW3  SW4  SW5        │  buttons, top face
        │                                  │
        │  ╔══════════════════════════╗    │
        │  ║  ESP32-S3-WROOM-1        ║    │  module rotated 90°,
   50mm │ ◄╢  antenna at LEFT edge    ║    │  antenna overhangs left
        │  ╚══════════════════════════╝    │  ← KEEPOUT: no copper
        │                                  │
        │   [JST]   [USB-C] [D3 chg LED]   │  one cutout covers both
        └────────── BOTTOM ────────────────┘

   Battery: 503035 cell (30 × 35 × 5mm) sits UNDER the board,
   lead exiting toward the bottom edge into J2.
```

Rotating the module puts the antenna on a long edge, which frees the bottom edge
for USB-C (the ergonomic place for a charge port) and keeps the connector's metal
shell well away from the radiating element. Antenna keepout: no copper on either
layer, no pour, under and beyond the antenna region.

Fat traces (≥1mm) VBAT → C1 → IR drivers for the 200mA pulses. USB D+/D− routed
as a loose differential pair, short, no stubs.

---

## 9. Gate 2 resolutions (all closed 2026-07-21)

| # | Question | Decision |
|---|---|---|
| 1 | LDO | **HT7833 SOT-89.** Not MCP1700 — do not substitute for lib convenience. ≥22µF bulk on 3V3 regardless. |
| 2 | Charge rate / cell | **R_PROG 4.7kΩ (212mA)**, 503035-class 400–500mAh, ~0.5C |
| 3 | Edges | **Approved** — IR LEDs top/front, USB-C bottom, antenna overhang left |
| 4 | Charge LED | **Keep**, placed adjacent to USB-C so one enclosure cutout covers both |
| 5 | BOOT/RESET | **Top-face tactiles** |
| — | Drivers, sense, pin map | AO3400 + 100Ω/100kΩ, GPIO1 ADC1, pin map as tabled — all approved |

**Still unverified and carried forward:** MCP73831 reverse battery drain (§7),
and every current figure in this document until boards are measured.

---

## 10. ERC status (Step 3)

`ir-remote.kicad_sch` — 42 components, 27 nets.

```
** ERC messages: 35   Errors 0   Warnings 35
```

**0 errors.** No unconnected pins, no conflicting drivers, no missing power
flags. Unused ESP32 GPIOs (25 of them) and the USB SBU pins carry explicit
no-connect flags rather than being left to float through ERC.

An earlier build had 83 violations; the extra 48 were `endpoint_off_grid`,
caused by placing symbols at arbitrary mm coordinates so pins missed KiCad's
1.27mm connectivity grid. That is not cosmetic — off-grid pins produce wires
that *look* connected but fail to join during later manual editing. Fixed by
rebuilding the schematic with every component on a 2.54mm grid.

### The 35 remaining warnings are all `lib_symbol_mismatch` — explained

The MCP writes symbol definitions in KiCad 6/7 syntax (`(pin_numbers hide)`,
`(in_bom yes)`) while KiCad 10's libraries use a newer form, so every cached
symbol trips the comparison. `kicad-cli sch upgrade` reformats the file but does
not resolve it.

**Verified benign rather than assumed benign.** I compared every pin number,
name, and coordinate in the schematic's symbol cache against the on-disk library
for all 12 symbols used:

| Result | Symbols |
|---|---|
| Pin sets identical | 10 of 12 — incl. ESP32-S3 (41 pins), USB-C (17), MCP73831, USBLC6, HT7833 |
| Differ | `Device:R`, `Device:C` — **name only**, `~` vs `""` for an unnamed pin |

Pin *numbers* and *positions* match everywhere, which is what determines the
netlist and the footprint mapping. Nothing electrical rides on this warning.
In KiCad, *Tools → Update Symbols from Library* clears it.

## 11. Layout + DRC status (Steps 4–5) — GATE 3

Board 30 × 50mm, 2-layer, 1.6mm, rounded 2mm corners. All 42 footprints placed,
GND pour on both layers with an antenna notch, thermal drills corrected.

### DRC progression

| Stage | Violations | What changed |
|---|---|---|
| After netlist sync | 2016 | nothing placed, all parts stacked at origin |
| After placement + pours | 83 | real floorplan |
| After re-spacing back side | 48 | **5 shorts → 0**, edge clearance 18 → 2 |
| After drill fix | **36** | 12 drill violations → 0 |

### Two real defects found and fixed

1. **Back-side parts were shorting.** I placed the power section on a 2.8mm
   pitch, but 0603 *HandSolder* pads are ~2.7mm long end-to-end, so neighbouring
   parts touched: R10/R11 (VBAT↔GND), R9/R12 (PROG↔BOOT), C9/C10 (VBUS↔GND),
   C8/R14. Re-spaced to 3.5mm.
2. **U1's thermal vias are 0.2mm drill — under JLCPCB's 0.3mm minimum.** The
   stock KiCad `ESP32-S3-WROOM-1` footprint ships 12 thermal PTH vias at 0.2mm,
   which standard 2-layer fab will not produce. Enlarged to 0.3mm in the board
   (0.15mm annular ring on the 0.6mm pad — within JLCPCB's 0.13mm minimum).
   **This is a footprint-level trap that would have come back as a fab query.**

Also caught: the stitching-via tool works off the *board outline*, not the pour
outline, and wanted to drop vias at (4.5, 28.5), (8.5, 33) and friends — **straight
through the antenna keepout.** Not used. Stitching vias are still outstanding and
must be placed zone-aware.

### Current state after routing (2026-07-21)

Board **30 × 58mm**, 2-layer. **DRC: 0 violations at JLCPCB rules.**
294 track segments, 78 vias, GND pours on both layers, 27 hand-placed
stitching vias.

| Check | Result |
|---|---|
| DRC (JLCPCB rules, zones filled) | **0 violations** |
| Antenna keepout — copper audit, independent of DRC | **0 intrusions** |
| Critical nets routed with fat traces | VBAT + IR1/IR2 at 0.6mm, 3V3/VBUS 0.5mm, USB pair 0.25mm |
| **Unconnected items** | **32 — NOT finished** |

Unconnected breakdown: **GND 32 endpoints, +3V3 8, VBUS 6, IR2_CTRL 2,
IR1_GATE 2, BTN1 2** — 26 unconnected items.

Three autorouter passes were run:

| Pass | Setup | Result |
|---|---|---|
| 1 | 50 passes, pours present | 25 of 27 nets, 114 wires |
| 2 | 100 passes, existing routing preserved | **regression** — 101 wires, net gain of 1 connection |
| 3 | 120 passes, **pours stripped so GND must route** | **did not converge; killed at ~35 min, no output** |

Pass 3 is the right approach and should be resumed with a longer budget, but it
is expensive: 59 GND pins on a dense 2-layer board is a much harder problem than
the signal nets. **The pours were restored afterwards so the board is not left
in a degraded state.**

**This board is not ready for fab.** Steps 6–7 (gerbers, BOM, CPL) remain on
hold.

#### The ground pour cannot carry GND on this board

Worth recording, because it is counter-intuitive and cost several iterations.

A ground pour on both layers plus 90 stitching vias still left ~32 GND endpoints
unconnected, and adding vias barely moved the number (44 → 42 → 38 → 34 → 32).
The cause: **the back side is too dense for the pour to weave through.** KiCad's
fill fragments into 14 pieces on F.Cu and 15 on B.Cu, and several GND pads sit in
regions the pour cannot reach at all — so no number of stitching vias helps,
because there is no pour fragment adjacent to those pads to stitch *to*.

Compounding it: **Freerouting exported the pours as planes and therefore assumed
GND was already connected**, emitting a single GND wire across two full routing
passes. The board had *zero* routed GND segments while looking plausible.

Fix: strip the zones, export DSN without them so GND becomes an ordinary
routable net (own class, 0.4mm), route, then restore the pours on top. The pours
then serve as shielding and extra copper rather than as the GND network itself.

**Lesson: on a dense 2-layer board, do not assume a pour equals connectivity.**
Check the routed-GND-segment count, not just the DRC unconnected number.

Two self-inflicted problems worth recording, both caught by verification rather
than by luck:

- **A wrong rotation transform.** I computed footprint pad positions with
  `gy = fy + px·sinθ + py·cosθ`; KiCad uses `gy = fy − px·sinθ + py·cosθ`. Every
  pad of the 90°-rotated ESP32 module was therefore checked at a mirrored
  position, so the first batch of stitching vias landed on top of U1's pads.
  Caught by DRC, fixed by deriving the transform from a pad whose true position
  KiCad had already reported.
- **An invalid token silently bricked the board file.** Adding
  `(min_resolved_spokes 1)` to the `.kicad_pcb` `(setup)` block made KiCad
  fail with a bare "Failed to load board" — no line number, no token name. That
  rule belongs in `.kicad_pro`, where setting it did work.

### ⚠️ Sizing history: 30 × 50mm was too small

The 36 remaining violations are not scattered — they are all one story:

| Count | Type | Cause |
|---|---|---|
| 15 | `courtyards_overlap` | SW4/SW5 against U1, J1 against J2/D3 |
| 13 | `items_not_allowed` | R13, SW1, SW4, SW6 sitting inside the ESP32 footprint's own **antenna keepout rule areas** |
| 6 | `clearance` | SW4/SW5 pads vs U1's top pad row |
| 2 | `copper_edge_clearance` | J1 shield pads at the edge — expected for an edge connector |

The module is 18 × 25.5mm and its antenna clearance zone (which the KiCad
footprint declares as 15 keepout areas) extends well beyond the body. Add 5
buttons, 2 unbrick buttons, 2 THT IR LEDs, USB-C and a JST on a 30 × 50mm
outline and there is simply no room left. **This is not fixable by nudging
parts — the outline has to grow.**

**Recommendation: 30 × 58mm** (+8mm on the long axis). That buys ~4mm between
the button block and the module, and moves R13/SW1/SW6 out of the antenna zone.
It still fits a shirt pocket and still suits the 503035 cell. **Tyler's call —
this deviates from the ≤30 × 50mm target in the brief.**

### Not done yet — stated plainly

- **Signal routing: 0 of 26 nets.** 107 unconnected items. Freerouting is
  unavailable on this machine (no Java 21 runtime, no Docker, no jar), so there
  is no autorouter; manual routing was not started because the outline question
  above changes every trace.
- **GND is handled by the pours**, not by routed traces — but the pours are
  unfilled (`refill_zones` carries a documented segfault risk on the SWIG
  backend and was not run).
- Stitching vias not placed (see above).
- Design rules not yet set to JLCPCB values — DRC above ran against KiCad
  defaults, which is what caught the 0.2mm drills.

**Nothing here is proven. No board has been fabricated.**

### ❌ Retracted: the "MCP destroys connectivity" finding was wrong

An earlier revision of this document claimed the kicad-mcp writer corrupted the
board's net table, and shipped a `fix-nets.py` to repair it. **That was a
misdiagnosis and both are withdrawn.**

KiCad 10 (board format `20260206`) references nets **by name** — `(net "GND")` —
having dropped the numeric index and the top-level `(net N "name")` table that
KiCad ≤ 9 used. `kicad-cli --save-board`, KiCad's own serialiser, writes exactly
that form, and DRC resolves it correctly. The MCP was right; the board was never
broken.

The false positive came from `grep '(net [0-9]'` returning zero, which looks
alarming but simply means this KiCad version no longer writes that form. The
"repair" converted the file to the legacy format, which KiCad still parses for
backward compatibility — so nothing visibly broke and the wrong diagnosis
appeared confirmed. It later introduced a real inconsistency (147 of 150 pad
refs disagreeing with its own rebuilt table), which is how it was caught.

Kept as a note because the failure mode is instructive: **a grep returning zero
is evidence about the grep, not proof about the tool.** See `README.md` for the
MCP traps that are real.

## 12. Firmware deltas this board forces

Not in scope for this brief, but recording so nothing is lost:

- Add BTN3–5 on GPIO 15/16/17 to the existing button scan.
- Add IR_CH2 on GPIO7 + a channel selector in the `trigger` GATT payload.
- Add `ext1_wakeup` with mask {2,5,15,16,17} and the sleep/send/sleep cycle.
- Add battery % from GPIO1 → report over the `status` characteristic.
- IR drive is now VBAT-referenced, not the 5V rail — the 33Ω breadboard value is
  obsolete and superseded by §5.

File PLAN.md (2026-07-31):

# IR-Remote — BLE-Programmable Universal Remote

**Goal:** Small 3–5 button universal remote. ESP32 WROOM sends IR codes; an iOS
"app" (web page opened in Bluefy) programs what each button does over BLE.
Codes sourced from Flipper-IRDB / irdb — no original remote needed.

**Created:** 2026-07-06 · **Hardware:** ESP32-S3 devkit + salvaged remote parts +
2× R13-507 16mm arcade momentary buttons (panel-mount, solder lugs — need jumper
wires soldered/clipped on for breadboarding; ideal for the final enclosure)

## Pin map (ESP32-S3)

| Signal | GPIO | Why |
|---|---|---|
| IR LED (via NPN) | 4 | Plain GPIO, RMT-capable |
| Button 1 | 5 | Physically wired to GPIO5 (bench-verified 2026-07-26). A GPIO6 firmware remap was tried but pin 6 was never actually wired, so button 1 went dead — reverted to GPIO5. RTC-capable, so EXT1 wake works |
| Button 2 | 2 | RTC-capable; GPIO5/6 also valid |
| Button 3 | 7 | RTC-capable, not a strapping pin (built on perf board 2026-07-26) |
| (Buttons 4–5 later) | 15, 16 | Same |

Avoid: 0/3/45/46 (strapping), 19/20 (USB), 26–37 (flash/PSRAM on many S3 modules).
Buttons wire GPIO→button→GND, `INPUT_PULLUP`, pressed = LOW.

⚠️ **GPIO2 is a strapping pin on the *classic* ESP32 but not on the S3** — most
"avoid these pins" lists online are written for the classic part. On the S3 the
strapping pins are only 0/3/45/46.

---

## Architecture

```
[iOS: Bluefy browser] ──Web Bluetooth──> [ESP32 BLE GATT]
                                              │ writes config to NVS (flash)
[physical buttons 3–5] ──GPIO──> [firmware] ──> [IR LED via NPN transistor]
                                              └──> TV / soundbar / etc.
```

- **Firmware:** Arduino framework + [IRremoteESP8266 v2.9.0](https://github.com/crankyoldgit/IRremoteESP8266)
  (despite the name, first-class ESP32 support; NEC/Sony/RC5/Samsung/etc.) +
  NimBLE-Arduino for BLE (lighter than Bluedroid).
- **BLE GATT design:** one service, two characteristics:
  - `config` (write): JSON like `{"btn":1,"proto":"NEC","code":"0x20DF10EF","bits":32}`
  - `status` (notify): ack / last-sent / battery
- **App:** single static HTML file using the Web Bluetooth API, opened in
  [Bluefy](https://apps.apple.com/us/app/bluefy-web-ble-browser/id1492822055) on iOS.
  Host on GitHub Pages (Web Bluetooth requires HTTPS). No Xcode, no signing.
- **Code source:** [Flipper-IRDB](https://github.com/Lucaslhm/Flipper-IRDB) —
  plain-text `.ir` files by brand/model. Paste protocol+code into the app; it
  writes to the ESP32.

## Salvage checklist (from donor remotes + devices)

| Part | Source | Notes |
|---|---|---|
| IR LED (940nm) | Any donor remote | Front of the PCB. Grab 2–3. |
| NPN transistor | Donor remote PCB | Drives the LED — ESP32 GPIO can't source enough current alone. If unsalvageable: 2N2222/S8050, pennies. |
| Tactile buttons | Remote PCB or other devices | Remote "buttons" are usually carbon-pad-on-membrane — NOT reusable as discrete switches. Salvage real tactile switches from other electronics, or use breadboard buttons. |
| Resistors | Any PCB | Need ~100–330Ω (LED current limit) + ~1kΩ (transistor base). |
| Battery contacts / holder | Donor remote shell | For Phase 4. |
| **IR receiver (TSOP38xx)** | TV / set-top box / DVD player — **NOT remotes** | Remotes only transmit. Optional: only needed to clone codes from physical remotes. Internet codes work without it. |

## Phases

**Phase 0 — Salvage audit.** ✅ Done.
**Phase 1 — IR transmit proof.** ✅ Done 2026-07-19 — Samsung TV toggled. Ran
direct GPIO drive (no NPN, ~13mA, inches of range) — transistor stage moved to Phase 3.
**Phase 2 — BLE + web app.** ✅ Done 2026-07-19 — TV toggled from a browser button.
Chrome → GATT → NVS → IR chain verified; artifacts `firmware/remote_ble/` +
`app/index.html`. GATT UUIDs and payload shapes recorded in docs/DEVLOG.md.
**Phase 2.5 — Bluefy on iPhone.** ✅ Done — iPhone → Bluefy → BLE → IR → TV verified.
**Phase 3 — NPN driver stage + physical buttons.** ✅ Done 2026-07-19. 2N2222 off
the 5V rail (33Ω, two IR LEDs in series, 1kΩ base) took range from ~5ft to
**20–30ft**. Button 1 (GPIO5) fires slot 1 standalone with no phone connected;
presses notify `pressed:N` and flash the slot in the app. Button 2 wired in
firmware on GPIO2, hardware not built yet.
**Phase 4 — Battery + deep sleep.** EXT1 wake on any button, send, sleep.
**Phase 5 — Enclosure.** Donor remote shell or printed case.

## Known tripwires

- **Phone-camera IR test:** the *front* (selfie) camera usually shows the IR LED
  flashing purple; main cameras often have IR filters and show nothing. Use the
  selfie cam before concluding the circuit is dead.
- **Never drive the IR LED straight off a GPIO.** GPIO max ~40mA absolute; decent
  IR range wants 100mA+ pulses through the transistor.
- **iOS Safari has no Web Bluetooth** — Bluefy (or WebBLE) is mandatory, not optional.
  The page must be served over HTTPS (GitHub Pages) for the API to be available.
- **AA-battery reality (Phase 4):** the devkit's AMS1117 LDO needs ~4.4V+ in, so
  3×AA works fresh but browns out as cells drain; and the devkit's USB-UART chip
  leaks mA even in deep sleep. Battery phase likely means 2×AA + boost converter,
  or a bare WROOM module. **Decision deferred — USB power through Phase 3.**
- **NVS, not EEPROM emulation** for stored codes — native, wear-leveled.

## Sources

- IRremoteESP8266 v2.9.0 (Jan 2026, ESP32 core 3.x support): https://github.com/crankyoldgit/IRremoteESP8266
- Bluefy Web BLE browser (active, v3.9.3 Jun 2026): https://apps.apple.com/us/app/bluefy-web-ble-browser/id1492822055
- Flipper-IRDB code database: https://github.com/Lucaslhm/Flipper-IRDB
- Official Flipper IRDB catalog: https://github.com/flipperdevices/IRDB

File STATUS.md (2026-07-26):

# IR-REMOTE — STATUS

**Status:** Active
**Updated:** 2026-07-26

## Where it's at
Phase 0 (salvage) done. **Phases 1, 2, 2.5 and 3 all COMPLETE** (2026-07-19).
Perf-board rebuild COMPLETE (2026-07-26). **Phase 5 Sitting A COMPLETE** (2026-07-26).

### Perf-board rebuild — ✅ COMPLETE (2026-07-26)
Circuit rebuilt from breadboard onto a perf board. Still USB power (boost/battery
not installed). **Three physical buttons now built: GPIO5 → slot 1, GPIO2 → slot 2,
GPIO7 → slot 3.** Bench session 2026-07-26 closed out every open fault from the
2026-07-21 stop; the board is a working across-the-room remote again.

- ✅ **IR range restored to across-the-room** — the pass gate is met. The
  2026-07-21 root cause (transistor E/C reversed, C→E measuring 3.4 V and only
  ~12 mA through the 33 Ω) is **fixed**: the 2N2222 was pulled, diode-tested good
  out of circuit (0.65 V leg = Emitter, 0.64 V leg = Collector), and reinstalled in
  the correct orientation. Verified 2026-07-26 with the `gpio4_on` steady-drive
  diagnostic: **both IR LEDs glow bright on a phone camera** (full ~100 mA), and a
  live walk-back range test toggled the TV at good distance. Both IR LEDs remain in
  the series loop.
- ✅ **Button 1 pin corrected: it's GPIO5, not GPIO6.** The uncommitted firmware
  had remapped button 1 to GPIO6 (on a since-disproven belief that pin 6 was wired).
  Boot printed `[btn] GPIO6 -> slot 1` cleanly, but **no press ever registered** —
  nothing is physically connected to pin 6; the wire is on GPIO5, button 1's
  original Phase 3 pin. Firmware reverted to GPIO5. All three buttons then verified
  on serial: `GPIO5 pressed -> slot 1 -> [ir] SAMSUNG 0xE0E040BF -> sent:1`, and
  buttons 2/3 correctly log `err:empty:N` for their unprogrammed slots. Clean single
  events, no chatter, no stuck-pressed signature.
  **Lesson:** a firmware pin map that prints clean at boot proves nothing about the
  wiring — a `pinMode`/label on an unconnected pin is silent, not an error. Confirm
  a button by a *press* event, not by the boot banner.
- ✅ **The "did I short something during rework" scare was transient.** A button's
  metal prong had briefly touched the board while powered. Power-off safety sweep
  (2026-07-26) came back clean: 5V↔GND and 3V3↔GND both open (the wandering
  MΩ/negative reading on the ohmmeter is the bulk cap charging, **not** a short — a
  real short sits pinned at single-digit Ω); no button line shorted to GND or 5V;
  LED path continuous with the 33 Ω correctly placed. No lasting damage. Across the
  whole session the serial showed **zero resets/brownouts/guru-meditations**.
- ✅ **33 Ω confirmed in the LED path, not the cap's branch.** The prior fault
  (33 Ω once wired in series with the bulk cap instead of the LED string) is **not**
  present — metered 5V→33Ω→LED1(+), and the cap connects rail-to-rail with plain
  wire. **Lesson:** a resistor can be physically present on the board and still not
  be in the current path; continuity to the right *node* is what matters, not that
  the part exists. (See `hardware/WIRING.md`, which encodes this.)
- ⚠️ **Intermittent BLE app disconnect — not a hardware fault, not chased down.**
  Bluefy dropped the link a couple of times mid-session but would not reproduce on
  demand; when connected, the full chain works (`config write -> nvs saved:1`,
  `trigger`/button -> `sent:1`). No board reset accompanies the drops, so it's a
  flaky BLE *link* (Web Bluetooth / Bluefy connection stability), not power or the
  IR path. Left as a known minor annoyance.
- ✅ **The "goes to protect" red light is solved and benign — it's capacitor
  inrush.** Tyler added a bulk/decoupling cap **across the 5V–GND rail, before the
  LED** (2026-07-21). On hot-plug the cap draws an inrush gulp that lights a
  charge/current LED, which fades as the cap charges — hence "on at plug-in, goes
  away on its own." The cap is **correctly placed and worth keeping** — it steadies
  the rail during the 64mA LED pulses. It is NOT in the 38kHz modulation path
  (GPIO4→base→transistor→LED), so it does **not** affect IR range. Chip probed
  healthy throughout (ESP32-S3 rev v0.2, 8MB PSRAM, MAC OK).
- Diagnostic sketches are regenerated per-session in the scratchpad (not the repo);
  `gpio4_on` (GPIO4 held HIGH for steady-drive metering / LED camera check) is the
  one used this session. ⚠️ It runs ~100 mA through the 33 Ω continuously — if that
  resistor is a 1/8 W part, don't leave the steady-drive sketch running long.

### Phase 5 — Code Library — Sitting A ✅ COMPLETE (2026-07-26)
Steps 1–4 of `docs/CC-BRIEF-phase5.md` (spec: `docs/DESIGN-code-library.md`).
Sitting B (steps 5–8: firmware direct-send + RC5/RC6/SONY, Identify mode,
Favorites) is a **separate session — not started**.

- **Scrape + convert (steps 1–2).** Re-scraped `Lucaslhm/Flipper-IRDB` fresh
  (shallow clone to a temp dir, not the repo) and hardened
  `tools/flipper_ir_convert.py`. New this sitting, per the design doc's
  field-feedback section:
    - **Search index** (`data/db/search.json`, 61 KB, 317 brand records): one
      compact record per brand (brand + category + canonical functions + model
      strings) so the app can search-first. Shards still lazy-load on selection.
    - **Generic / blanket codes.** Model-spread is measured before dedupe; a
      canonical code shared across ≥3 models in a brand is flagged `generic`
      (with `nmodels`). These are the universal-remote sweet spot. E.g. Samsung
      TV `0xE0E040BF` = power_toggle across 36 models.
    - **Sweep ordering** now prefers `power_on` before toggle before `power_off`
      (an already-on device shouldn't flicker off mid-sweep).
  DB totals: 8 categories, 317 brands, ~13.8K codes. All sanity gates pass
  (Samsung `0xE0E040BF` present; NEC projector discrete on/off; generics
  promoted; search index indexes Samsung TVs).
- **App (step 3), `app/index.html`, still one file / vanilla JS.**
    - **Search-first** is the front door (live, debounced, ranked brand hits);
      the Category→Brand→Model dropdowns are kept as a collapsible fallback.
    - Brand view shows **generic/blanket codes at the top**, then all codes
      ordered with **discrete power_on/power_off before power_toggle** (toggle is
      tagged "fallback"). Assigning a code binds the **whole brand keymap** to a
      slot; manual hex entry retained.
    - **Show-the-code-that-was-sent:** a physical press now reports
      `button N sent → <friendly name> (PROTO CODE)` in the status bar, and slot
      readouts are named when the code came from the library.
  Verified end-to-end in desktop Chrome (search → open Samsung TVs → assign
  `0xE0E040BF` → slot 1 named readout); no app JS errors.
- **Bench pass gate (step 4) MET:** a library-picked Samsung power code, saved
  from the app, toggles the bench TV at full distance.
- ⚠️ **Known follow-up — intermittent BLE disconnect.** Bluefy/Web-Bluetooth
  link drops with `reason 520` (supervision timeout); when congested, an app
  Save drags and times out mid-write, which *looks* like "save broke it." Serial
  proved the stored code + IR transmit are always correct (`SAMSUNG 0xE0E040BF`
  before and after Save) — this is a link-stability issue, **not** data or IR.
  Good candidate to investigate in Sitting B alongside the firmware work.
- Note: during enclosure fitting a button prong shorted the board twice (transient
  each time); reflash + clean boot every time. Heat-shrink insulation added.

### Phase 3 — NPN driver stage + physical buttons ✅

**Circuit as built** (fed from the devkit's 5V/VBUS pin):
```
5V ──33Ω──► IR LED1 (+)─(−) ──► IR LED2 (+)─(−) ──► COLLECTOR
GPIO4 ──1kΩ──► BASE                                 EMITTER ──► GND
```
- Transistor **2N2222**, TO-92 plastic. Pinout identified empirically with a
  multimeter (diode mode) rather than assumed — E/C order varies by vendor even
  for the same part number. Middle pin is Base; of the outer two, the one reading
  the *higher* forward drop from Base is the Emitter.
- **Two salvaged IR LEDs in series** (the second tested as a genuine IR emitter on
  a selfie cam, not a red indicator). ~64mA pulses, vs ~13mA on the old direct
  GPIO drive.
- Buttons: **GPIO5 → slot 1**, **GPIO2 → slot 2**, `INPUT_PULLUP`, pin→button→GND.
  (Perf-board rebuild moved button 1 to **GPIO6** — see the perf-board section below.)

**Pass-gate results:**
- ✅ **Range: ~5ft → 20–30ft.** The single biggest win of the phase.
- ✅ Physical button 1 toggles the TV from across the room.
- ✅ **Standalone** — works with Bluefy fully disconnected. It is a real remote,
  not a BLE accessory.
- ✅ Debounce verified clean at millisecond resolution: one press → exactly one
  event, no chatter. (A Samsung frame takes **109ms** to transmit — measured.)
- ✅ `pressed:1` notifies the app and flashes the matching slot row.
- ⏭️ **Button 2 not built** — no second button on hand. (Earlier note claimed GPIO6
  wasn't broken out on this devkit and moved button 2 to GPIO2; that claim was
  **wrong** — GPIO6 is broken out and works, see perf-board section. GPIO2 remains a
  fine alternate for button 2.)

**Phase 2 pass gate met: the TV toggled from a button in the browser.** Full chain
verified end to end — Chrome (Web Bluetooth) → BLE GATT write → JSON parse → NVS →
IR send → real device. Serial confirmed each layer:
```
[ble] config write: {"slot":1,"proto":"SAMSUNG","code":"0xE0E040BF","bits":32}
[nvs] slot 1 <- SAMSUNG 0xE0E040BF (32 bits)   [status] saved:1
[ble] trigger write: {"slot":1}
[ir]  slot 1 -> SAMSUNG 0xE0E040BF (32 bits)   [status] sent:1
```
NVS persistence proven by power-cycling: second boot skipped seeding and read
slot 1 back from flash.

**Phase 1 pass gate met** earlier the same day: the Samsung TV toggled power.
`firmware/phase1_ir_test` sends `0xE0E040BF` (`sendSAMSUNG`, 32 bits) on GPIO4
every 3s. Kept in the repo as the minimal known-good IR proof.

### Phase 2 artifacts
- `firmware/remote_ble/remote_ble.ino` — BLE GATT + IR, 5 NVS-backed slots
- `app/index.html` — self-contained Web Bluetooth app, no build step

**GATT — device name `IR-Remote`:**

| Role | UUID |
|---|---|
| service | `b457c32b-22b1-425f-8a88-4d6dc37ba4eb` |
| `config` (WRITE) | `d997012d-7d2b-47de-ae87-bae14df446ef` |
| `trigger` (WRITE) | `58397514-04a3-4265-9590-9d910c4e99d2` |
| `status` (NOTIFY) | `b8ddfe01-519f-430d-bd4e-aba0dd852e2c` |

`config` payload `{"slot":1,"proto":"SAMSUNG","code":"0xE0E040BF","bits":32}`
(slots 1–5; protocols NEC, SAMSUNG, SONY). `trigger` payload `{"slot":1}`.
`status` notifies `saved:N` / `sent:N` / `err:...`.

**Run the web app locally:**
```
cd ~/dev/ir-remote/app && python3 -m http.server 8000
```
Open `http://localhost:8000` in **desktop Chrome** — `localhost` counts as a secure
context, so Web Bluetooth works without HTTPS. Safari has no Web Bluetooth, ever.

**Range is only a few inches** — expected, not a defect. Direct GPIO drive
(GPIO4 → 150Ω → LED → GND) is ~13mA where a real remote pulses its LED at 100mA+.
The NPN stage in PLAN.md is what buys range; add it before Phase 3.

### Toolchain (macOS)
- `arduino-cli` 1.5.1 (Homebrew)
- esp32 core **3.3.10**, IRremoteESP8266 **2.9.0**
- Native USB CDC port, FQBN `esp32:esp32:esp32s3:CDCOnBoot=cdc`.
  **Port number is not stable** — seen as both `usbmodem2101` and `usbmodem1101`
  across replugs/jacks. Re-check with `arduino-cli board list` before flashing.

```
arduino-cli compile --fqbn esp32:esp32:esp32s3:CDCOnBoot=cdc firmware/phase1_ir_test
arduino-cli upload -p <PORT> --fqbn esp32:esp32:esp32s3:CDCOnBoot=cdc firmware/phase1_ir_test
sleep 20 | arduino-cli monitor -p <PORT> -c baudrate=115200
```

## Next step
**Phase 5 Sitting B** (`docs/CC-BRIEF-phase5.md` steps 5–8) — a separate session:
firmware direct-send `{"proto","code","bits"}` + RC5/RC6/SONY in the send switch;
Identify mode (sweep power codes ~400ms apart → last-5 re-send → keymap unlock);
Favorites (☆ rows, localStorage + JSON export/import, push-to-slot). The sweep
lists (`data/sweep-*.json`) and generic/search data from Sitting A already feed it.
- While in there, investigate the **intermittent BLE disconnect** (`reason 520`
  supervision timeout — see the Phase 5 Sitting A note). Link stability, not data.

Perf-board rebuild and Phase 5 Sitting A are both done (2026-07-26).

Then **Phase 4 — battery + deep sleep.** EXT1 wake on the button pins, now
**GPIO5 + GPIO2 + GPIO7** on the perf board (all RTC-capable on the S3, which EXT1
requires). Wake → send → sleep.

Open questions carried in from PLAN.md's tripwires: the devkit's AMS1117 LDO wants
~4.4V+ in, and the onboard USB-UART chip leaks mA even in deep sleep — so this
likely means 2×AA + a boost converter, or moving to a bare WROOM module. The
circuit currently runs off **5V/VBUS, which only exists while USB is plugged in**;
battery power changes that rail and the 33Ω value should be rechecked against
whatever new supply voltage is chosen.

Buttons 1–3 are now built (GPIO5/GPIO2/GPIO7); slots 2 and 3 are unprogrammed
(they log `err:empty:N` until a code is written to them).

## Blocked on
Nothing. Phases 1 and 2 both fully verified, including their physical pass gates.

### RESOLVED — web app couldn't find the board over BLE
Symptom: Chrome's device chooser scanned forever, found nothing, while the board's
serial insisted it was advertising.
**Cause: BLE advertising payload overflow.** The advertisement is capped at 31
bytes; flags (3) + a 128-bit service UUID (18) + the name `IR-Remote` (11) = 32.
The name was silently dropped/truncated, so the app's `filters: [{name: ...}]`
could never match. Nothing was wrong with the Mac or the hardware.
**Fix, both sides:** firmware now puts the UUID in the advertisement and the name
in the *scan response* (its own 31 bytes) via explicit `NimBLEAdvertisementData`;
the app filters on `services: [SERVICE_UUID]` instead of the name.
**Lesson:** a 128-bit UUID leaves almost no room in an advertisement — put the name
in the scan response and filter by service UUID, never by name.

### RESOLVED — "LED doesn't light from GPIO4"
Symptom: LED lit when wired to 3V3, appeared dead when driven from GPIO4.
**Not a fault.** The two tests aren't comparable — 3V3 is a steady glow, while the
IR send is a ~70ms burst of 38kHz-modulated pulses once every 3s, far too brief and
dim to catch by eye on a selfie cam. Confirmed by flashing a steady-drive test
(GPIO4 HIGH 3s / LOW 3s, no modulation): LED lit normally. Diagnostic sketches kept
out of the repo, in the session scratchpad.
**Reusable trick:** to test the LED/GPIO path, drive the pin steady — never judge
the drive path by watching a modulated IR burst.

### RESOLVED — board was stuck in ROM download mode
Kept for reference; this signature is easy to misread as a firmware failure.
After live-soldering, every sketch went silent. Diagnosis (2026-07-18):
- Chip is healthy: ESP32-S3 rev v0.2, 8MB flash, eFuse 3.3V, MAC reads, stub
  flasher runs. Flash image verified intact ("No changed sectors found").
- Not a brownout/LED short: a diagnostic sketch that never drives GPIO4 was
  equally silent, ruling that out.
- **Decisive test:** `esptool --before no-reset --after no-reset flash-id` synced
  successfully — the chip was *already* in the bootloader with nothing having
  reset it. It never reaches the application.
- **Cause: GPIO0 (BOOT) held LOW at reset** — the strapping pin PLAN.md warns
  about. Suspects, in order: BOOT button stuck/bridged; solder bridge onto GPIO0;
  a stray wire landed on pin 0 instead of pin 4.
- **Fix was physical** (freeing GPIO0), and it worked — board now boots the app
  normally. Reflash was never needed; flash reported "No changed sectors found"
  every time, i.e. the image was correct throughout.
- **Lesson:** silent serial + flash-verifies-clean + uploads that never need the
  BOOT/RESET dance == stuck in download mode. Test it with
  `esptool --before no-reset --after no-reset flash-id`: if it syncs with nothing
  having reset the chip, it was already parked in the bootloader. Don't reflash —
  check the strapping pins.

## Notes

### KiCad 10 changed the board net format — don't "fix" it

Applies to the PCB work in `hardware/`. **This entry exists to stop someone
(including me, again) from repairing a non-bug.**

KiCad 10 (board format `20260206`) references nets **by name**:
```
(net "GND")        <- pads, tracks and vias, KiCad 10
```
The numeric index and the top-level `(net N "name")` declaration table that
KiCad ≤ 9 used are **gone**. `kicad-cli --save-board` — KiCad's own serialiser —
writes exactly this, and DRC resolves it correctly (`Pad 5 [BTN1]`,
`Track [BTN1]`).

I originally mistook this for a kicad-mcp bug, on the strength of
`grep '(net [0-9]'` returning zero, and wrote a script to "repair" it. The
script converted the board to the legacy format. KiCad still accepts that for
backward compatibility, so nothing visibly broke — which is what made the wrong
diagnosis look confirmed. It was deleted.

**If a net grep looks wrong, check what format this KiCad version writes before
concluding a tool is broken.** Verify with:
```
kicad-cli pcb drc --output /tmp/drc.rpt hardware/ir-remote.kicad_pcb
grep -A3 unconnected /tmp/drc.rpt      # nets appear as [GND], [BTN1] etc. when healthy
```

**Real MCP trap that does apply:** editing the board file outside the MCP makes
its next auto-save *refuse* (mtime guard, `diskChangedExternally`), so your edits
live only in server memory until they're lost. Call `open_project` to re-sync
before further MCP edits.

Freerouting and antenna-keepout traps are in `hardware/README.md`.

- **RESOLVED 2026-07-19 — `arduino.cc` network block.** On 2026-07-18 the whole of
  `arduino.cc` was unreachable (DNS resolved, TLS reset — SNI/IP filtering, not a
  sandbox artifact), which broke `core update-index` and `lib install`. Worked
  around by patching `package_esp32_index.json` to drop the `arduino:dfu-util`
  dependency and hand-installing IRremoteESP8266 from its GitHub release tag.
  **All of that is now undone and no longer applies** — Tyler moved to a private
  network. Index restored from backup, both indexes refreshed, `esp32:esp32`
  reinstalled cleanly with `dfu-util` present, and IRremoteESP8266 2.9.0
  reinstalled through the library manager so it's properly tracked. No local
  patches remain; `core update-index` is safe to run.
  The block briefly returned mid-session — the Mac had been auto-joining a bad
  network — which is why NimBLE-Arduino 2.5.0 and ArduinoJson 7.4.3 were installed
  from GitHub release tags rather than `arduino-cli lib install`. Network since
  fixed; `arduino.cc` verified reachable again. GitHub and Espressif hosts were
  never affected. **Root cause was the network, never the toolchain** — if
  downloads start failing again, check the Wi-Fi before touching arduino-cli.
- **Library install fallback** (when `arduino.cc` is blocked): download the release
  zip from GitHub into `~/Documents/Arduino/libraries/<LibName>`. Verify with
  `grep '^version' <LibName>/library.properties`.
- **Wiring deviates from PLAN.md on purpose:** GPIO4 → 150Ω → IR LED → GND, no NPN.
  That's ~13mA vs the 100mA+ pulses the transistor drive is for, so **range will be
  inches, not across the room.** If the TV doesn't toggle at close range, suspect the
  drive current before suspecting the code. Add the transistor stage before Phase 3.
- `arduino-cli monitor` exits instantly if stdin is closed (it forwards stdin to the
  port) — hold stdin open (`sleep 20 | arduino-cli monitor ...`) when scripting it.
- USB CDC buffers output while no host is attached, so the first several `sent` lines
  dump in a burst on connect. Timestamp the stream to read the true cadence.
- USB power through Phase 3; battery decision deferred (see tripwires in PLAN.md).
- Possibly this is the "Remote-App" slot from the master dashboard — confirm and
  give it its one-line definition there if so.

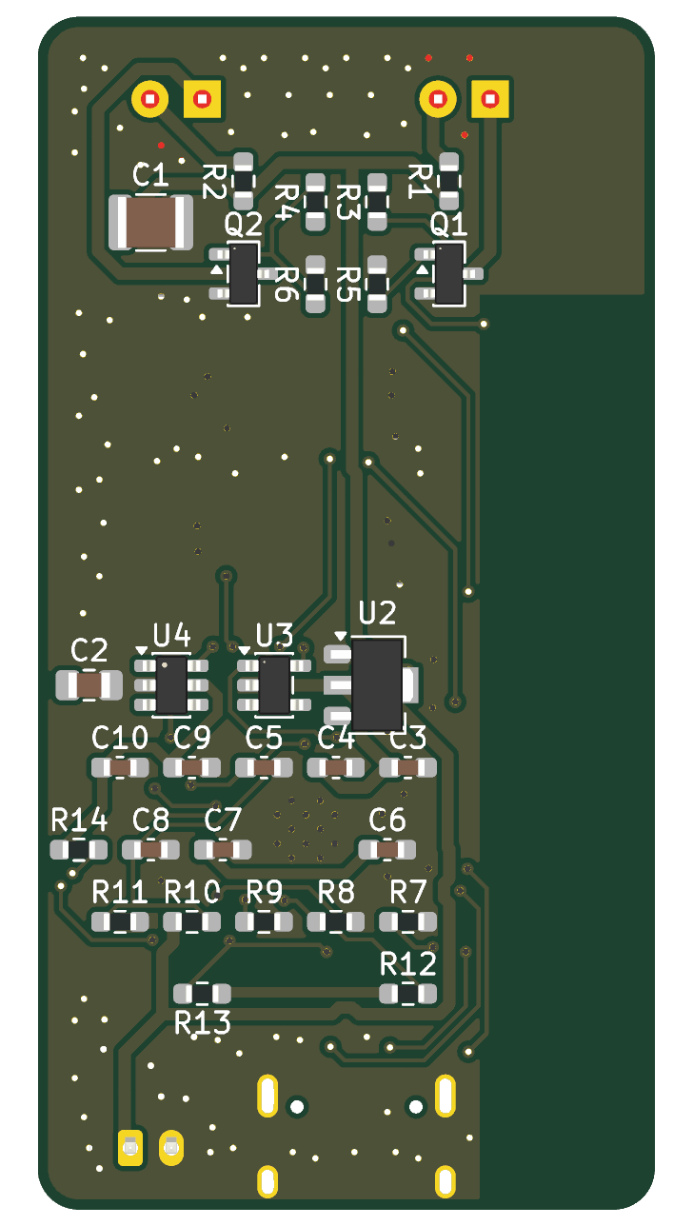
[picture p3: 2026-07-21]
hardware/layout-bottom.png

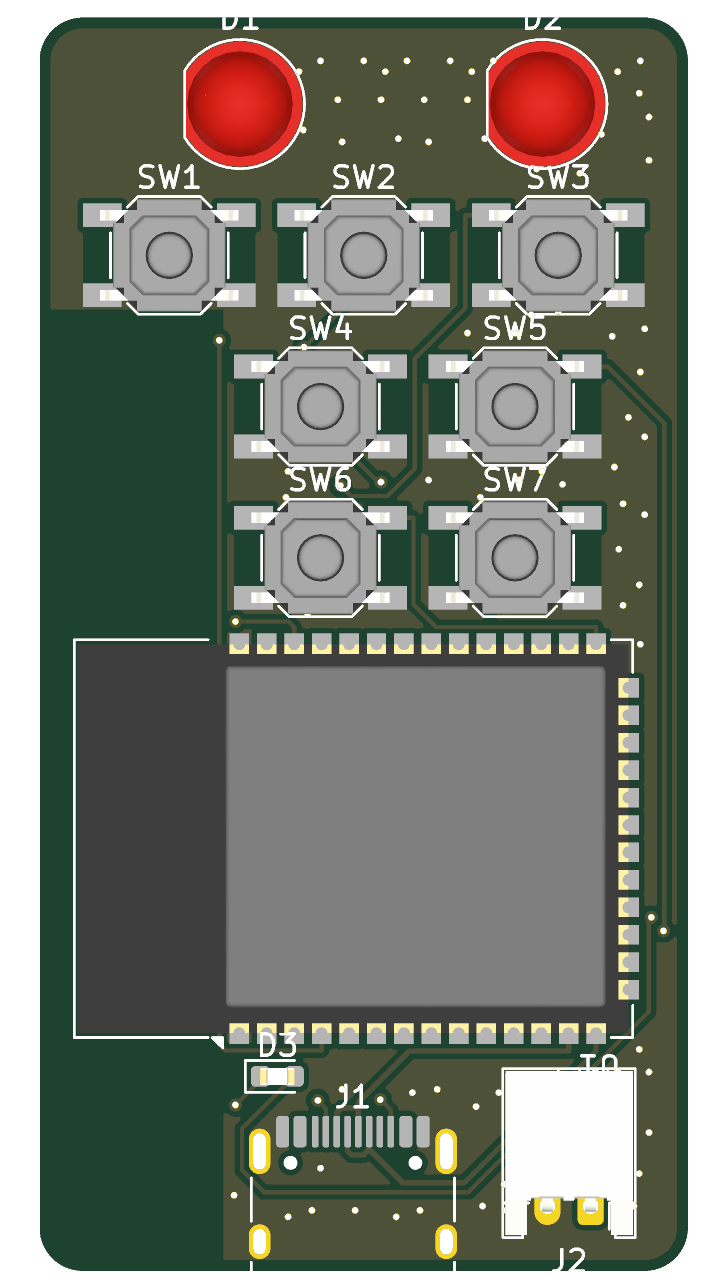
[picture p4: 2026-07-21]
hardware/layout-top.png

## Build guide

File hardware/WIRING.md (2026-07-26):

# Wiring Card — perf-board build (canonical quick reference)

USB-powered perf board, ESP32-S3 devkit socketed. One glance, no archaeology.

```
POWER
  Devkit 5V pin ──► 5V rail
  Devkit GND    ──► GND rail
  470µF cap across the rails: (+) → 5V, (−) stripe → GND. Near the driver.
  (Cap is parallel — NOTHING routes through it. The 33Ω must NOT be in the
  cap's branch; that was the unlimited-current incident of 2026-07.)

IR DRIVER (2N2222, TO-92)
  5V rail ──33Ω──► LED1 anode(+)
  LED1(−) ──► LED2(+)                 [series pair, both 940nm emitters]
  LED2(−) ──► COLLECTOR
  EMITTER ──► GND rail
  GPIO4 ──1kΩ──► BASE (middle leg)

  E vs C by meter (diode mode, red probe on Base, black on each outer):
  HIGHER forward drop = EMITTER → GND. Lower = COLLECTOR → LED2(−).
  Vendor leg order varies — always meter, never assume.

BUTTONS (R13-507, two-lug, no polarity, no resistor)
  Button 1: GPIO5 ──► button ──► GND     → slot 1  (NOT GPIO6 — pin 6 was never
            wired; a firmware GPIO6 remap made btn1 go dead. Verified 2026-07-26.)
  Button 2: GPIO2 ──► button ──► GND     → slot 2  (slot unprogrammed)
  Button 3: GPIO7 ──► button ──► GND     → slot 3  (slot unprogrammed)
  Firmware uses INPUT_PULLUP; pressed = LOW.

HEALTH CHECKS
  Idle GPIO5→GND: ~3.3V; pressed: 0V.
  Driver on (steady-drive test): C→E ≈ 0.2V, across 33Ω ≈ 3.3V (~100mA).
    C→E ≈ 3.4V + 33Ω ≈ 0.4V  == transistor E/C reversed (seen 2026-07-21).
  5V↔GND unpowered: open, never ~0Ω.
  LED path: beep 5V→33Ω→LED1→LED2→collector; NO direct 5V→LED1 beep.
```

Phase 4 (battery) will replace the POWER block only; everything below it stays.

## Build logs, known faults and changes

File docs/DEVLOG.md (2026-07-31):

# IR-REMOTE — STATUS

**Status:** Active
**Updated:** 2026-07-26

## Where it's at
Phase 0 (salvage) done. **Phases 1, 2, 2.5 and 3 all COMPLETE** (2026-07-19).
Perf-board rebuild COMPLETE (2026-07-26). **Phase 5 Sitting A COMPLETE** (2026-07-26).

### Public release prep — ✅ COMPLETE (2026-07-31)

The repo was public but unusable by a stranger: no LICENSE (so nobody could
legally reuse it) and no README (so nobody could understand or build it). Both
fixed.

- **Licensed MIT** (`LICENSE`, © 2026 Tyler Koontz).
- **The GPL-3.0 problem, and why files were deleted.** Licenses verified from
  source, not assumed: `Lucaslhm/Flipper-IRDB` is **CC0-1.0** (public domain
  dedication — the whole of `data/db/`, 317 brands, imposes no obligations), but
  `data/source/tv.ir` and `projectors.ir` came from
  `DarkFlippers/unleashed-firmware`, which is **GPL-3.0**. GPL-3.0 is copyleft:
  shipping those files, or anything derived from them, forces the whole project
  to GPL-3.0. MIT and GPL-3.0 cannot coexist in one distribution. So the two
  `.ir` files, their converted `data/tv.json` / `data/projectors.json`, and the
  converter's `--sweep-from` code path were all removed.
  ⚠️ **They remain in earlier commits — history was NOT rewritten.** That is
  deliberate and proportionate: the files are gone going forward, and the
  situation is disclosed in `README.md` and `data/README.md`. Do not force-push
  to "clean" this later; it would break every existing clone to no real benefit.
- **Sweep lists rebuilt from CC0 data only.** `build_sweep_from_db()` replaces
  `build_sweep()`: it sums each power code's model-spread across every brand in
  a category — the same blanket-code signal the brand view already uses, widened
  from one brand to a category — dedupes by `(proto, code)`, and sorts
  `power_on → power_toggle → power_off`, spread-descending within each group.
  Same five-key output schema; **the app's data contract did not change.**
  - **TV: 130 → 70 codes. Projector: 51 → 57.** The TV list genuinely shrank.
    Checked before accepting it: of the 69 dropped TV codes, **53 do not exist
    anywhere in Flipper-IRDB** (Unleashed-only data, unrecoverable), and the
    high-spread head of the list is fully intact — LG `NEC 0x20DF10EF` (57
    models), Samsung `0xE0E040BF` (39), Sony `0x95` (27). What was lost is the
    one-model tail. Widening the sweep to every category was measured and
    rejected: 241 codes and a 96-second sweep to recover 4 more of the old list.
    Decision: ship the 70. Shorter sweep, same practical hit rate.
  - `tv` draws from `tvs` + `monitors` because the app already maps monitors
    onto the TV sweep file.
- **All four sanity gates pass** on a fresh end-to-end scrape (317 brands,
  11,148 parsed codes, byte-identical `data/db/` — the scrape is deterministic).
- **`README.md`** — what-it-is, perf board photos (`docs/images/`), the live
  Pages link with the Bluefy/Web Bluetooth explanation, BOM, wiring, build+flash
  with pinned tool versions, and an honest status table.
- **Reconciled with the GitHub-side restructuring** done in parallel (13
  commits): `STATUS.md` → `docs/DEVLOG.md`, all seven `CC-BRIEF-*.md` files
  deleted, and a first README written in the GitHub UI. That README's
  unauthenticated-GATT security note and the Ko-fi link were kept and grafted
  into this one; its licensing section was superseded, since it described the
  repo as GPL-encumbered and recommended GPL-3.0. `data/source/ATTRIBUTION.md`
  went with the rest of `data/source/`, its substance folded into
  `data/README.md`. The 13 commits were rebased under, not merged over — nothing
  was force-pushed or discarded.
- **`data/README.md` added** — DB layout, entry schema, provenance, and the
  regenerate command with its sanity gates.
- **The dev board in the photos is a Seeed Studio XIAO ESP32-S3** (readable on
  the silkscreen). PLAN.md and this file had only ever said "ESP32-S3 devkit";
  the README now names the actual part.

**Not tagged.** A release waits for the PCB or Phase 5 completion — unchanged.

**Left uncommitted on purpose:** the Phase 5 **Sitting B** work in progress
(`app/index.html` Identify mode + Favorites, `firmware/remote_ble` direct-send +
RC5/RC6/SONY). It is written but has **never been run against hardware**, since
the board died before it could be tested. It is not part of the release commit.

### ☠️ DEVKIT KILLED during first battery attempt (2026-07-27) — replace and resume

**The board is dead.** 3V3↔GND measures **3 Ω with a continuous beep** — a hard
short inside the devkit (onboard regulator or the S3 itself). Nothing on the perf
board touches 3V3, so the fault is entirely in the devkit. The blinking red power
LED is the signature: the 5 V rail collapses into the shorted 3.3 V rail, browns
out, retries, forever. There was visible smoke. Not repairable — swap the devkit.

**ROOT CAUSE (confirmed 2026-07-27): the boost converter was outputting 9 V, not
5 V.** It's a cheap module whose output voltage is selected by a **solder blob
across selector pads**. Tyler set it to 5 V and verified it the day before; when
re-measured after the failure it read **9 V**. The blob had let go (cold joint —
these modules typically default to their highest setting when the selection
opens). 9 V into the devkit's 5 V pin puts the whole overage across the onboard
3.3 V regulator, which cooks and fails **short** — which is precisely the 3 Ω
3V3↔GND reading and the smoke. The earlier "loose battery leads shorted" theory
was wrong; the leads were a hazard but not the killer.

**Contributing sequence:**
1. Battery + boost wired to the 5 V rail; cell was flat, so nothing came up.
2. USB plugged in while the battery leads were still connected — two sources on
   one rail (bad practice, not the fatal blow).
3. Battery removed but bare lead ends left attached; USB re-plugged; the boost,
   now silently at 9 V, put 9 V on the rail → smoke.

**Action taken:** the cheap solder-blob-selectable boosters are retired from this
project. Better modules only from here.

**Rules for the replacement board — do not skip:**
- ⚠️ **One power source at a time.** Never USB and battery/boost simultaneously
  unless the devkit is known to have a VBUS protection diode. Put a **slide
  switch in the battery line** so switching sources is a flick, not a rewire.
- ⚠️ **Never leave bare supply leads attached to a powered board.** Terminate
  them (connector), insulate them, or remove them entirely. A dangling live
  lead is a short waiting for gravity.
- ⚠️ **Re-verify boost output voltage EVERY session, not once.** This is the
  lesson that actually cost the board: a solder-blob voltage selector can open
  between sessions and silently jump to 9 V. Meter OUT+/OUT− before every
  connection, and prefer modules with a fixed 5 V output or a trimmer you can
  lock down — not blob-selectable ones. Verify under load; open-circuit lies.
- **Charge the cell first.** A flat LiPo makes the boost strain and invites
  exactly the "is it even working?" fiddling that caused this.
- Socket the devkit (it was) so a swap is a pull, not a desolder.

**What survived:** firmware + app committed and pushed; code library live on
GitHub Pages; slot config is a 2-minute reprogram from the app; the driver
circuit (2N2222, 33 Ω, both IR LEDs, bulk cap) all metered clean — the 448 Ω
reading across 5V↔GND was just the bulk cap charging, not a fault.

**Resume:** drop in a fresh ESP32-S3 devkit, reflash `firmware/remote_ble`,
reprogram slot 1 from the app, confirm the across-the-room range test. Then
Phase 5 Sitting B (software, no bench risk) and Phase 4 battery — this time with
the switch and the rules above.

### Perf-board rebuild — ✅ COMPLETE (2026-07-26)
Circuit rebuilt from breadboard onto a perf board. Still USB power (boost/battery
not installed). **Three physical buttons now built: GPIO5 → slot 1, GPIO2 → slot 2,
GPIO7 → slot 3.** Bench session 2026-07-26 closed out every open fault from the
2026-07-21 stop; the board is a working across-the-room remote again.

- ✅ **IR range restored to across-the-room** — the pass gate is met. The
  2026-07-21 root cause (transistor E/C reversed, C→E measuring 3.4 V and only
  ~12 mA through the 33 Ω) is **fixed**: the 2N2222 was pulled, diode-tested good
  out of circuit (0.65 V leg = Emitter, 0.64 V leg = Collector), and reinstalled in
  the correct orientation. Verified 2026-07-26 with the `gpio4_on` steady-drive
  diagnostic: **both IR LEDs glow bright on a phone camera** (full ~100 mA), and a
  live walk-back range test toggled the TV at good distance. Both IR LEDs remain in
  the series loop.
- ✅ **Button 1 pin corrected: it's GPIO5, not GPIO6.** The uncommitted firmware
  had remapped button 1 to GPIO6 (on a since-disproven belief that pin 6 was wired).
  Boot printed `[btn] GPIO6 -> slot 1` cleanly, but **no press ever registered** —
  nothing is physically connected to pin 6; the wire is on GPIO5, button 1's
  original Phase 3 pin. Firmware reverted to GPIO5. All three buttons then verified
  on serial: `GPIO5 pressed -> slot 1 -> [ir] SAMSUNG 0xE0E040BF -> sent:1`, and
  buttons 2/3 correctly log `err:empty:N` for their unprogrammed slots. Clean single
  events, no chatter, no stuck-pressed signature.
  **Lesson:** a firmware pin map that prints clean at boot proves nothing about the
  wiring — a `pinMode`/label on an unconnected pin is silent, not an error. Confirm
  a button by a *press* event, not by the boot banner.
- ✅ **The "did I short something during rework" scare was transient.** A button's
  metal prong had briefly touched the board while powered. Power-off safety sweep
  (2026-07-26) came back clean: 5V↔GND and 3V3↔GND both open (the wandering
  MΩ/negative reading on the ohmmeter is the bulk cap charging, **not** a short — a
  real short sits pinned at single-digit Ω); no button line shorted to GND or 5V;
  LED path continuous with the 33 Ω correctly placed. No lasting damage. Across the
  whole session the serial showed **zero resets/brownouts/guru-meditations**.
- ✅ **33 Ω confirmed in the LED path, not the cap's branch.** The prior fault
  (33 Ω once wired in series with the bulk cap instead of the LED string) is **not**
  present — metered 5V→33Ω→LED1(+), and the cap connects rail-to-rail with plain
  wire. **Lesson:** a resistor can be physically present on the board and still not
  be in the current path; continuity to the right *node* is what matters, not that
  the part exists. (See `hardware/WIRING.md`, which encodes this.)
- ⚠️ **Intermittent BLE app disconnect — not a hardware fault, not chased down.**
  Bluefy dropped the link a couple of times mid-session but would not reproduce on
  demand; when connected, the full chain works (`config write -> nvs saved:1`,
  `trigger`/button -> `sent:1`). No board reset accompanies the drops, so it's a
  flaky BLE *link* (Web Bluetooth / Bluefy connection stability), not power or the
  IR path. Left as a known minor annoyance.
- ✅ **The "goes to protect" red light is solved and benign — it's capacitor
  inrush.** Tyler added a bulk/decoupling cap **across the 5V–GND rail, before the
  LED** (2026-07-21). On hot-plug the cap draws an inrush gulp that lights a
  charge/current LED, which fades as the cap charges — hence "on at plug-in, goes
  away on its own." The cap is **correctly placed and worth keeping** — it steadies
  the rail during the 64mA LED pulses. It is NOT in the 38kHz modulation path
  (GPIO4→base→transistor→LED), so it does **not** affect IR range. Chip probed
  healthy throughout (ESP32-S3 rev v0.2, 8MB PSRAM, MAC OK).
- Diagnostic sketches are regenerated per-session in the scratchpad (not the repo);
  `gpio4_on` (GPIO4 held HIGH for steady-drive metering / LED camera check) is the
  one used this session. ⚠️ It runs ~100 mA through the 33 Ω continuously — if that
  resistor is a 1/8 W part, don't leave the steady-drive sketch running long.

### Phase 5 — Code Library — Sitting A ✅ COMPLETE (2026-07-26)
Steps 1–4 of `docs/CC-BRIEF-phase5.md` (spec: `docs/DESIGN-code-library.md`).
Sitting B (steps 5–8: firmware direct-send + RC5/RC6/SONY, Identify mode,
Favorites) is a **separate session — not started**.

- **Scrape + convert (steps 1–2).** Re-scraped `Lucaslhm/Flipper-IRDB` fresh
  (shallow clone to a temp dir, not the repo) and hardened
  `tools/flipper_ir_convert.py`. New this sitting, per the design doc's
  field-feedback section:
    - **Search index** (`data/db/search.json`, 61 KB, 317 brand records): one
      compact record per brand (brand + category + canonical functions + model
      strings) so the app can search-first. Shards still lazy-load on selection.
    - **Generic / blanket codes.** Model-spread is measured before dedupe; a
      canonical code shared across ≥3 models in a brand is flagged `generic`
      (with `nmodels`). These are the universal-remote sweet spot. E.g. Samsung
      TV `0xE0E040BF` = power_toggle across 36 models.
    - **Sweep ordering** now prefers `power_on` before toggle before `power_off`
      (an already-on device shouldn't flicker off mid-sweep).
  DB totals: 8 categories, 317 brands, ~13.8K codes. All sanity gates pass
  (Samsung `0xE0E040BF` present; NEC projector discrete on/off; generics
  promoted; search index indexes Samsung TVs).
- **App (step 3), `app/index.html`, still one file / vanilla JS.**
    - **Search-first** is the front door (live, debounced, ranked brand hits);
      the Category→Brand→Model dropdowns are kept as a collapsible fallback.
    - Brand view shows **generic/blanket codes at the top**, then all codes
      ordered with **discrete power_on/power_off before power_toggle** (toggle is
      tagged "fallback"). Assigning a code binds the **whole brand keymap** to a
      slot; manual hex entry retained.
    - **Show-the-code-that-was-sent:** a physical press now reports
      `button N sent → <friendly name> (PROTO CODE)` in the status bar, and slot
      readouts are named when the code came from the library.
  Verified end-to-end in desktop Chrome (search → open Samsung TVs → assign
  `0xE0E040BF` → slot 1 named readout); no app JS errors.
- **Bench pass gate (step 4) MET:** a library-picked Samsung power code, saved
  from the app, toggles the bench TV at full distance.
- ⚠️ **Known follow-up — intermittent BLE disconnect.** Bluefy/Web-Bluetooth
  link drops with `reason 520` (supervision timeout); when congested, an app
  Save drags and times out mid-write, which *looks* like "save broke it." Serial
  proved the stored code + IR transmit are always correct (`SAMSUNG 0xE0E040BF`
  before and after Save) — this is a link-stability issue, **not** data or IR.
  Good candidate to investigate in Sitting B alongside the firmware work.
- Note: during enclosure fitting a button prong shorted the board twice (transient
  each time); reflash + clean boot every time. Heat-shrink insulation added.

### Phase 3 — NPN driver stage + physical buttons ✅

**Circuit as built** (fed from the devkit's 5V/VBUS pin):
```
5V ──33Ω──► IR LED1 (+)─(−) ──► IR LED2 (+)─(−) ──► COLLECTOR
GPIO4 ──1kΩ──► BASE                                 EMITTER ──► GND
```
- Transistor **2N2222**, TO-92 plastic. Pinout identified empirically with a
  multimeter (diode mode) rather than assumed — E/C order varies by vendor even
  for the same part number. Middle pin is Base; of the outer two, the one reading
  the *higher* forward drop from Base is the Emitter.
- **Two salvaged IR LEDs in series** (the second tested as a genuine IR emitter on
  a selfie cam, not a red indicator). ~64mA pulses, vs ~13mA on the old direct
  GPIO drive.
- Buttons: **GPIO5 → slot 1**, **GPIO2 → slot 2**, `INPUT_PULLUP`, pin→button→GND.
  (Perf-board rebuild moved button 1 to **GPIO6** — see the perf-board section below.)

**Pass-gate results:**
- ✅ **Range: ~5ft → 20–30ft.** The single biggest win of the phase.
- ✅ Physical button 1 toggles the TV from across the room.
- ✅ **Standalone** — works with Bluefy fully disconnected. It is a real remote,
  not a BLE accessory.
- ✅ Debounce verified clean at millisecond resolution: one press → exactly one
  event, no chatter. (A Samsung frame takes **109ms** to transmit — measured.)
- ✅ `pressed:1` notifies the app and flashes the matching slot row.
- ⏭️ **Button 2 not built** — no second button on hand. (Earlier note claimed GPIO6
  wasn't broken out on this devkit and moved button 2 to GPIO2; that claim was
  **wrong** — GPIO6 is broken out and works, see perf-board section. GPIO2 remains a
  fine alternate for button 2.)

**Phase 2 pass gate met: the TV toggled from a button in the browser.** Full chain
verified end to end — Chrome (Web Bluetooth) → BLE GATT write → JSON parse → NVS →
IR send → real device. Serial confirmed each layer:
```
[ble] config write: {"slot":1,"proto":"SAMSUNG","code":"0xE0E040BF","bits":32}
[nvs] slot 1 <- SAMSUNG 0xE0E040BF (32 bits)   [status] saved:1
[ble] trigger write: {"slot":1}
[ir]  slot 1 -> SAMSUNG 0xE0E040BF (32 bits)   [status] sent:1
```
NVS persistence proven by power-cycling: second boot skipped seeding and read
slot 1 back from flash.

**Phase 1 pass gate met** earlier the same day: the Samsung TV toggled power.
`firmware/phase1_ir_test` sends `0xE0E040BF` (`sendSAMSUNG`, 32 bits) on GPIO4
every 3s. Kept in the repo as the minimal known-good IR proof.

### Phase 2 artifacts
- `firmware/remote_ble/remote_ble.ino` — BLE GATT + IR, 5 NVS-backed slots
- `app/index.html` — self-contained Web Bluetooth app, no build step

**GATT — device name `IR-Remote`:**

| Role | UUID |
|---|---|
| service | `b457c32b-22b1-425f-8a88-4d6dc37ba4eb` |
| `config` (WRITE) | `d997012d-7d2b-47de-ae87-bae14df446ef` |
| `trigger` (WRITE) | `58397514-04a3-4265-9590-9d910c4e99d2` |
| `status` (NOTIFY) | `b8ddfe01-519f-430d-bd4e-aba0dd852e2c` |

`config` payload `{"slot":1,"proto":"SAMSUNG","code":"0xE0E040BF","bits":32}`
(slots 1–5; protocols NEC, SAMSUNG, SONY). `trigger` payload `{"slot":1}`.
`status` notifies `saved:N` / `sent:N` / `err:...`.

**Run the web app locally:**
```
cd app && python3 -m http.server 8000
```
Open `http://localhost:8000` in **desktop Chrome** — `localhost` counts as a secure
context, so Web Bluetooth works without HTTPS. Safari has no Web Bluetooth, ever.

**Range is only a few inches** — expected, not a defect. Direct GPIO drive
(GPIO4 → 150Ω → LED → GND) is ~13mA where a real remote pulses its LED at 100mA+.
The NPN stage in PLAN.md is what buys range; add it before Phase 3.

### Toolchain (macOS)
- `arduino-cli` 1.5.1 (Homebrew)
- esp32 core **3.3.10**, IRremoteESP8266 **2.9.0**
- Native USB CDC port, FQBN `esp32:esp32:esp32s3:CDCOnBoot=cdc`.
  **Port number is not stable** — seen as both `usbmodem2101` and `usbmodem1101`
  across replugs/jacks. Re-check with `arduino-cli board list` before flashing.

```
arduino-cli compile --fqbn esp32:esp32:esp32s3:CDCOnBoot=cdc firmware/phase1_ir_test
arduino-cli upload -p <PORT> --fqbn esp32:esp32:esp32s3:CDCOnBoot=cdc firmware/phase1_ir_test
sleep 20 | arduino-cli monitor -p <PORT> -c baudrate=115200
```

## Next step
**Phase 5 Sitting B** — spec is `docs/DESIGN-code-library.md` (the per-session
`CC-BRIEF-*.md` files were removed from the repo on 2026-07-31; the Sitting B
brief survives only in git history, at commit `377163c`). A separate session:
firmware direct-send `{"proto","code","bits"}` + RC5/RC6/SONY in the send switch;
Identify mode (sweep power codes ~400ms apart → last-5 re-send → keymap unlock);
Favorites (☆ rows, localStorage + JSON export/import, push-to-slot). The sweep
lists (`data/sweep-*.json`) and generic/search data from Sitting A already feed it.
- While in there, investigate the **intermittent BLE disconnect** (`reason 520`
  supervision timeout — see the Phase 5 Sitting A note). Link stability, not data.

Perf-board rebuild and Phase 5 Sitting A are both done (2026-07-26).

Then **Phase 4 — battery + deep sleep.** EXT1 wake on the button pins, now
**GPIO5 + GPIO2 + GPIO7** on the perf board (all RTC-capable on the S3, which EXT1
requires). Wake → send → sleep.

Open questions carried in from PLAN.md's tripwires: the devkit's AMS1117 LDO wants
~4.4V+ in, and the onboard USB-UART chip leaks mA even in deep sleep — so this
likely means 2×AA + a boost converter, or moving to a bare WROOM module. The
circuit currently runs off **5V/VBUS, which only exists while USB is plugged in**;
battery power changes that rail and the 33Ω value should be rechecked against
whatever new supply voltage is chosen.

Buttons 1–3 are now built (GPIO5/GPIO2/GPIO7); slots 2 and 3 are unprogrammed
(they log `err:empty:N` until a code is written to them).

## Blocked on
Nothing. Phases 1 and 2 both fully verified, including their physical pass gates.

### RESOLVED — web app couldn't find the board over BLE
Symptom: Chrome's device chooser scanned forever, found nothing, while the board's
serial insisted it was advertising.
**Cause: BLE advertising payload overflow.** The advertisement is capped at 31
bytes; flags (3) + a 128-bit service UUID (18) + the name `IR-Remote` (11) = 32.
The name was silently dropped/truncated, so the app's `filters: [{name: ...}]`
could never match. Nothing was wrong with the Mac or the hardware.
**Fix, both sides:** firmware now puts the UUID in the advertisement and the name
in the *scan response* (its own 31 bytes) via explicit `NimBLEAdvertisementData`;
the app filters on `services: [SERVICE_UUID]` instead of the name.
**Lesson:** a 128-bit UUID leaves almost no room in an advertisement — put the name
in the scan response and filter by service UUID, never by name.

### RESOLVED — "LED doesn't light from GPIO4"
Symptom: LED lit when wired to 3V3, appeared dead when driven from GPIO4.
**Not a fault.** The two tests aren't comparable — 3V3 is a steady glow, while the
IR send is a ~70ms burst of 38kHz-modulated pulses once every 3s, far too brief and
dim to catch by eye on a selfie cam. Confirmed by flashing a steady-drive test
(GPIO4 HIGH 3s / LOW 3s, no modulation): LED lit normally. Diagnostic sketches kept
out of the repo, in the session scratchpad.
**Reusable trick:** to test the LED/GPIO path, drive the pin steady — never judge
the drive path by watching a modulated IR burst.

### RESOLVED — board was stuck in ROM download mode
Kept for reference; this signature is easy to misread as a firmware failure.
After live-soldering, every sketch went silent. Diagnosis (2026-07-18):
- Chip is healthy: ESP32-S3 rev v0.2, 8MB flash, eFuse 3.3V, MAC reads, stub
  flasher runs. Flash image verified intact ("No changed sectors found").
- Not a brownout/LED short: a diagnostic sketch that never drives GPIO4 was
  equally silent, ruling that out.
- **Decisive test:** `esptool --before no-reset --after no-reset flash-id` synced
  successfully — the chip was *already* in the bootloader with nothing having
  reset it. It never reaches the application.
- **Cause: GPIO0 (BOOT) held LOW at reset** — the strapping pin PLAN.md warns
  about. Suspects, in order: BOOT button stuck/bridged; solder bridge onto GPIO0;
  a stray wire landed on pin 0 instead of pin 4.
- **Fix was physical** (freeing GPIO0), and it worked — board now boots the app
  normally. Reflash was never needed; flash reported "No changed sectors found"
  every time, i.e. the image was correct throughout.
- **Lesson:** silent serial + flash-verifies-clean + uploads that never need the
  BOOT/RESET dance == stuck in download mode. Test it with
  `esptool --before no-reset --after no-reset flash-id`: if it syncs with nothing
  having reset the chip, it was already parked in the bootloader. Don't reflash —
  check the strapping pins.

## Notes

### KiCad 10 changed the board net format — don't "fix" it

Applies to the PCB work in `hardware/`. **This entry exists to stop someone
(including me, again) from repairing a non-bug.**

KiCad 10 (board format `20260206`) references nets **by name**:
```
(net "GND")        <- pads, tracks and vias, KiCad 10
```
The numeric index and the top-level `(net N "name")` declaration table that
KiCad ≤ 9 used are **gone**. `kicad-cli --save-board` — KiCad's own serialiser —
writes exactly this, and DRC resolves it correctly (`Pad 5 [BTN1]`,
`Track [BTN1]`).

I originally mistook this for a kicad-mcp bug, on the strength of
`grep '(net [0-9]'` returning zero, and wrote a script to "repair" it. The
script converted the board to the legacy format. KiCad still accepts that for
backward compatibility, so nothing visibly broke — which is what made the wrong
diagnosis look confirmed. It was deleted.

**If a net grep looks wrong, check what format this KiCad version writes before
concluding a tool is broken.** Verify with:
```
kicad-cli pcb drc --output /tmp/drc.rpt hardware/ir-remote.kicad_pcb
grep -A3 unconnected /tmp/drc.rpt      # nets appear as [GND], [BTN1] etc. when healthy
```

**Real MCP trap that does apply:** editing the board file outside the MCP makes
its next auto-save *refuse* (mtime guard, `diskChangedExternally`), so your edits
live only in server memory until they're lost. Call `open_project` to re-sync
before further MCP edits.

Freerouting and antenna-keepout traps are in `hardware/README.md`.

- **RESOLVED 2026-07-19 — `arduino.cc` network block.** On 2026-07-18 the whole of
  `arduino.cc` was unreachable (DNS resolved, TLS reset — SNI/IP filtering, not a
  sandbox artifact), which broke `core update-index` and `lib install`. Worked
  around by patching `package_esp32_index.json` to drop the `arduino:dfu-util`
  dependency and hand-installing IRremoteESP8266 from its GitHub release tag.
  **All of that is now undone and no longer applies** — Tyler moved to a private
  network. Index restored from backup, both indexes refreshed, `esp32:esp32`
  reinstalled cleanly with `dfu-util` present, and IRremoteESP8266 2.9.0
  reinstalled through the library manager so it's properly tracked. No local
  patches remain; `core update-index` is safe to run.
  The block briefly returned mid-session — the Mac had been auto-joining a bad
  network — which is why NimBLE-Arduino 2.5.0 and ArduinoJson 7.4.3 were installed
  from GitHub release tags rather than `arduino-cli lib install`. Network since
  fixed; `arduino.cc` verified reachable again. GitHub and Espressif hosts were
  never affected. **Root cause was the network, never the toolchain** — if
  downloads start failing again, check the Wi-Fi before touching arduino-cli.
- **Library install fallback** (when `arduino.cc` is blocked): download the release
  zip from GitHub into `~/Documents/Arduino/libraries/<LibName>`. Verify with
  `grep '^version' <LibName>/library.properties`.
- **Wiring deviates from PLAN.md on purpose:** GPIO4 → 150Ω → IR LED → GND, no NPN.
  That's ~13mA vs the 100mA+ pulses the transistor drive is for, so **range will be
  inches, not across the room.** If the TV doesn't toggle at close range, suspect the
  drive current before suspecting the code. Add the transistor stage before Phase 3.
- `arduino-cli monitor` exits instantly if stdin is closed (it forwards stdin to the
  port) — hold stdin open (`sleep 20 | arduino-cli monitor ...`) when scripting it.
- USB CDC buffers output while no host is attached, so the first several `sent` lines
  dump in a burst on connect. Timestamp the stream to read the true cadence.
- USB power through Phase 3; battery decision deferred (see tripwires in PLAN.md).
- Possibly this is the "Remote-App" slot from the master dashboard — confirm and
  give it its one-line definition there if so.

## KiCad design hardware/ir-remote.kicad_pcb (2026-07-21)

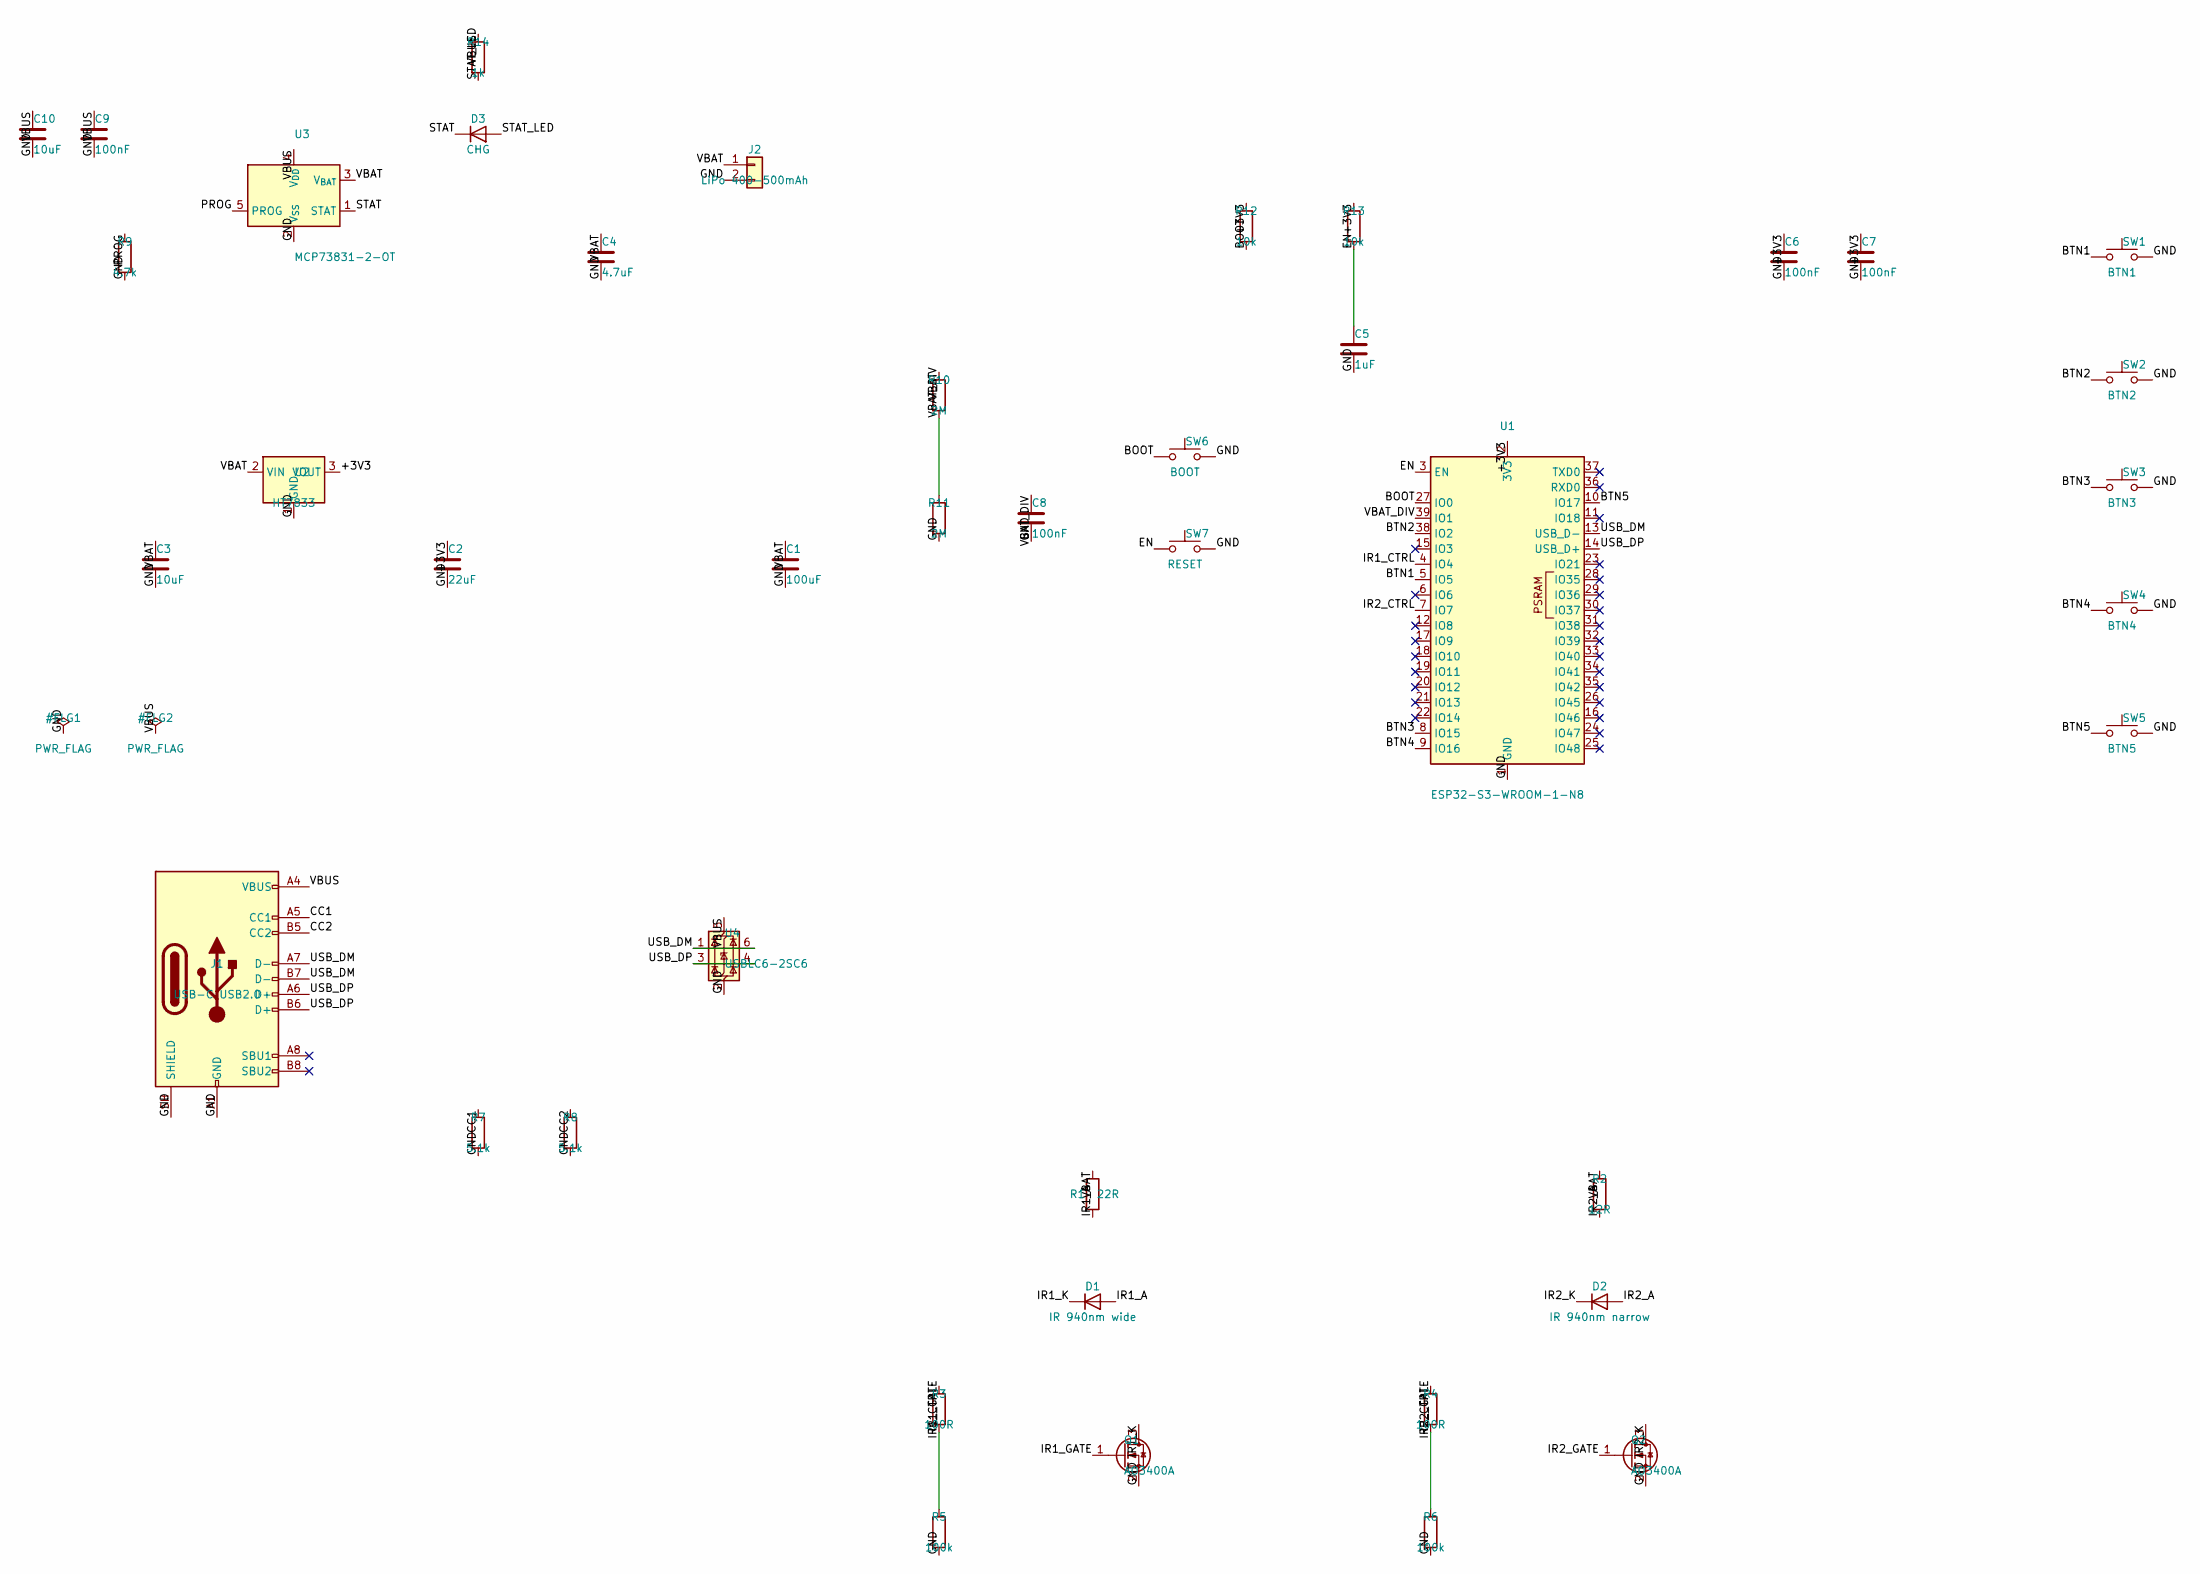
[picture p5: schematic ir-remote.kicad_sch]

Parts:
C1: 100uF; C_1210_3225Metric
C2: 22uF; C_0805_2012Metric_Pad1.18x1.45mm_HandSolder
C3, C10: 10uF; C_0603_1608Metric_Pad1.08x0.95mm_HandSolder
C4: 4.7uF; C_0603_1608Metric_Pad1.08x0.95mm_HandSolder
C5: 1uF; C_0603_1608Metric_Pad1.08x0.95mm_HandSolder
C6, C7, C8, C9: 100nF; C_0603_1608Metric_Pad1.08x0.95mm_HandSolder
D1: IR 940nm wide; LED_D5.0mm
D2: IR 940nm narrow; LED_D5.0mm
D3: CHG; LED_0603_1608Metric
J1: USB-C USB2.0; USB_C_Receptacle_HRO_TYPE-C-31-M-12
J2: LiPo 400-500mAh; JST_PH_S2B-PH-K_1x02_P2.00mm_Horizontal
Q1, Q2: AO3400A; SOT-23
R1: 22R; R_0603_1608Metric_Pad0.98x0.95mm_HandSolder
R2: 12R; R_0603_1608Metric_Pad0.98x0.95mm_HandSolder
R3, R4: 100R; R_0603_1608Metric_Pad0.98x0.95mm_HandSolder
R5, R6: 100k; R_0603_1608Metric_Pad0.98x0.95mm_HandSolder
R7, R8: 5.1k; R_0603_1608Metric_Pad0.98x0.95mm_HandSolder
R9: 4.7k; R_0603_1608Metric_Pad0.98x0.95mm_HandSolder
R10, R11: 2M; R_0603_1608Metric_Pad0.98x0.95mm_HandSolder
R12, R13: 10k; R_0603_1608Metric_Pad0.98x0.95mm_HandSolder
R14: 1k; R_0603_1608Metric_Pad0.98x0.95mm_HandSolder
SW1: BTN1; SW_SPST_SKQG_WithStem
SW2: BTN2; SW_SPST_SKQG_WithStem
SW3: BTN3; SW_SPST_SKQG_WithStem
SW4: BTN4; SW_SPST_SKQG_WithStem
SW5: BTN5; SW_SPST_SKQG_WithStem
SW6: BOOT; SW_SPST_SKQG_WithStem
SW7: RESET; SW_SPST_SKQG_WithStem
U1: ESP32-S3-WROOM-1-N8; ESP32-S3-WROOM-1
U2: HT7833; SOT-89-3
U3: MCP73831-2-OT; SOT-23-5
U4: USBLC6-2SC6; SOT-23-6

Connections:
+3V3: C2.1, C6.1, C7.1, R12.1, R13.1, U1.2 (3V3), U2.3 (VOUT)
BOOT: R12.2, SW6.1, U1.27 (IO0)
BTN1: SW1.1, U1.5 (IO5)
BTN2: SW2.1, U1.38 (IO2)
BTN3: SW3.1, U1.8 (IO15)
BTN4: SW4.1, U1.9 (IO16)
BTN5: SW5.1, U1.10 (IO17)
CC1: J1.A5 (CC1), R7.1
CC2: J1.B5 (CC2), R8.1
EN: C5.1, R13.2, SW7.1, U1.3 (EN)
GND: C1.2, C2.2, C3.2, C4.2, C5.2, C6.2, C7.2, C8.2, C9.2, C10.2, J1.A1 (GND), J1.A12 (GND), J1.B1 (GND), J1.B12 (GND), J1.SH (SHIELD), J2.2, Q1.2 (S), Q2.2 (S), R5.2, R6.2, R7.2, R8.2, R9.2, R11.2, SW1.2, SW2.2, SW3.2, SW4.2, SW5.2, SW6.2, SW7.2, U1.1 (GND), U1.40 (GND), U1.41 (GND), U2.1 (GND), U3.2 (V_{SS}), U4.2 (GND)
IR1_A: D1.2 (A), R1.2
IR1_CTRL: R3.1, U1.4 (IO4)
IR1_GATE: Q1.1 (G), R3.2, R5.1
IR1_K: D1.1 (K), Q1.3 (D)
IR2_A: D2.2 (A), R2.2
IR2_CTRL: R4.1, U1.7 (IO7)
IR2_GATE: Q2.1 (G), R4.2, R6.1
IR2_K: D2.1 (K), Q2.3 (D)
PROG: R9.1, U3.5 (PROG)
STAT: D3.1 (K), U3.1 (STAT)
STAT_LED: D3.2 (A), R14.2
USB_DM: J1.A7 (D-), J1.B7 (D-), U1.13 (USB_D-), U4.1 (I/O1), U4.6 (I/O1)
USB_DP: J1.A6 (D+), J1.B6 (D+), U1.14 (USB_D+), U4.3 (I/O2), U4.4 (I/O2)
VBAT: C1.1, C3.1, C4.1, J2.1, R1.1, R2.1, R10.1, U2.2 (VIN), U3.3 (V_{BAT})
VBAT_DIV: C8.1, R10.2, R11.1, U1.39 (IO1)
VBUS: C9.1, C10.1, J1.A4 (VBUS), J1.A9 (VBUS), J1.B4 (VBUS), J1.B9 (VBUS), R14.1, U3.4 (V_{DD}), U4.5 (VBUS)

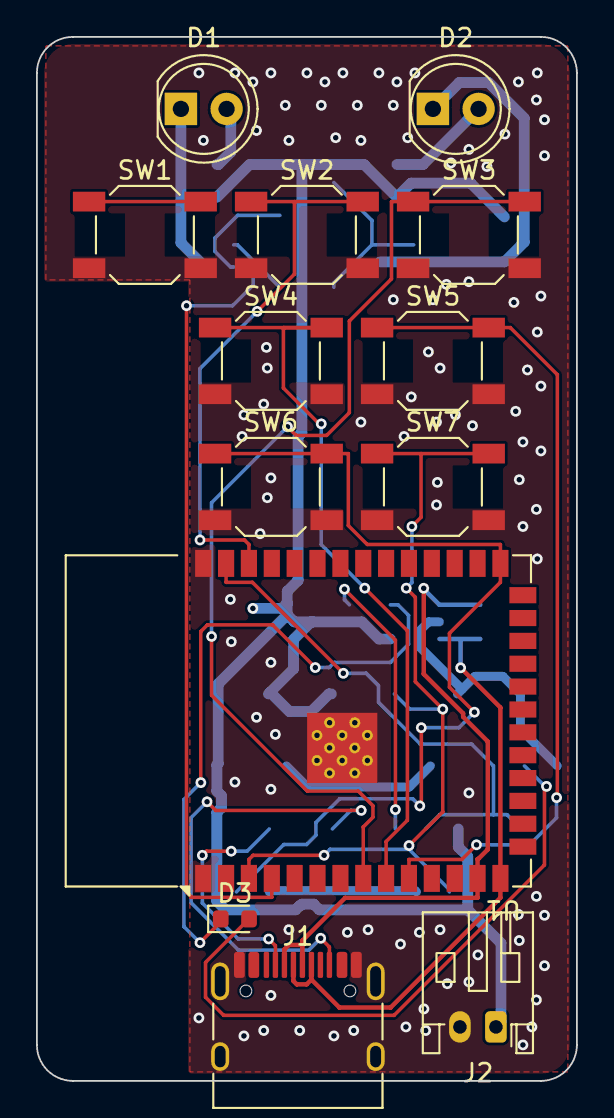
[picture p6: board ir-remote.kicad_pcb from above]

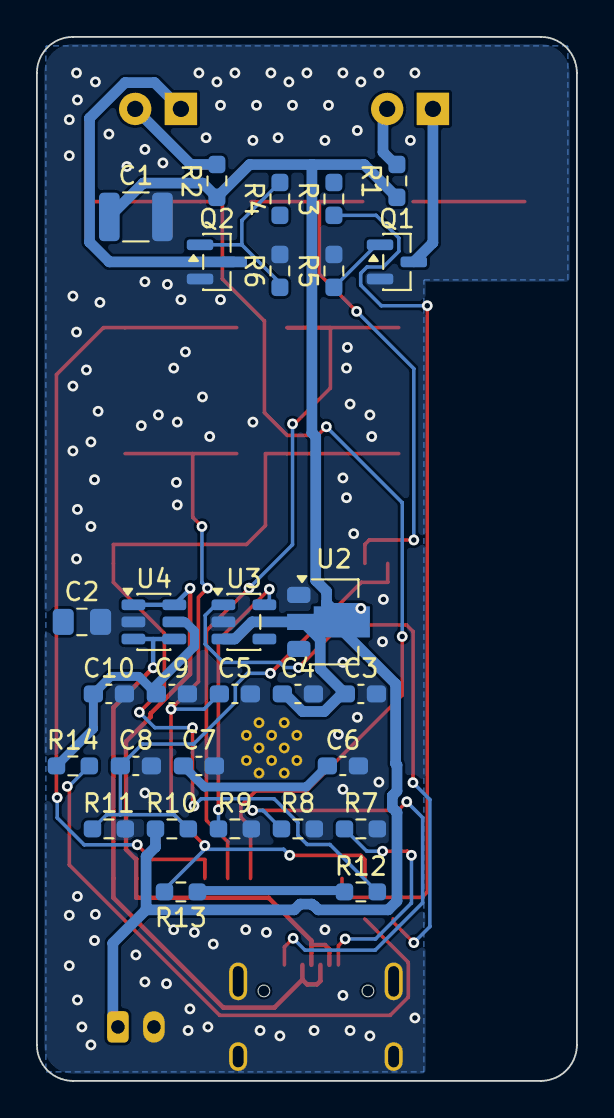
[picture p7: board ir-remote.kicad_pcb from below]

Board: 2 copper layers, 30.0 x 58.0 mm, 42 parts (29 on the bottom side), 27 nets.

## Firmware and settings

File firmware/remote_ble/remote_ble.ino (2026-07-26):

/*
 * Phase 2 — BLE GATT + programmable IR slots (ESP32-S3)
 *
 * Keeps Phase 1's IR send path (GPIO4, IRremoteESP8266) and adds a BLE GATT
 * service so a Web Bluetooth app can program and fire five IR slots.
 * Slot config persists in NVS via Preferences, so it survives a power cycle.
 *
 * GATT — service b457c32b-22b1-425f-8a88-4d6dc37ba4eb, device name "IR-Remote":
 *   config  (WRITE)  {"slot":1,"proto":"SAMSUNG","code":"0xE0E040BF","bits":32}
 *   trigger (WRITE)  {"slot":1}
 *   status  (NOTIFY) "saved:1" / "sent:1" / "err:..."
 *
 * Phase 3 hardware — NPN driver stage off the 5V rail, ~64mA through two IR
 * LEDs in series (was ~13mA on direct GPIO drive, inches of range; now 20-30ft):
 *   5V --33R--> LED1(+)-(-) --> LED2(+)-(-) --> COLLECTOR
 *   GPIO4 --1k--> BASE           EMITTER --> GND
 *
 * Phase 3 buttons: GPIO5 -> slot 1, GPIO2 -> slot 2. INPUT_PULLUP, wired
 * pin -> button -> GND, so pressed reads LOW. Fixed mapping, button N -> slot N.
 * Buttons work with no BLE client connected — the remote is standalone.
 */

#include <Arduino.h>
#include <NimBLEDevice.h>
#include <Preferences.h>
#include <ArduinoJson.h>
#include <IRremoteESP8266.h>
#include <IRsend.h>

// ── UUIDs (generated once, hardcoded — the web app must match these) ─────────
#define SERVICE_UUID "b457c32b-22b1-425f-8a88-4d6dc37ba4eb"
#define CONFIG_UUID  "d997012d-7d2b-47de-ae87-bae14df446ef"
#define TRIGGER_UUID "58397514-04a3-4265-9590-9d910c4e99d2"
#define STATUS_UUID  "b8ddfe01-519f-430d-bd4e-aba0dd852e2c"

static const uint16_t kIrLedPin   = 4;
static const uint8_t  kMinSlot    = 1;
static const uint8_t  kMaxSlot    = 5;
static const char*    kDevName    = "IR-Remote";
static const uint32_t kDebounceMs = 30;

// Button N -> slot N, fixed mapping. Pressed = LOW (INPUT_PULLUP to GND).
struct ButtonState {
  uint8_t  pin;
  uint8_t  slot;
  int      stable;        // debounced level; HIGH = released
  int      lastRead;
  uint32_t lastChangeMs;
};

// Perf-board build: button 1 is physically wired to GPIO5 (verified on the
// bench 2026-07-26 — a GPIO6 map printed clean at boot but no press ever
// registered, because nothing is connected to pin 6; the wire is on pin 5,
// button 1's original Phase 3 pin). GPIO5 is RTC-capable (S3 RTC pins are 0-21)
// so Phase 4's EXT1 deep-sleep wake still works. The custom PCB uses its own
// pin map (see hardware/DESIGN-pcb.md).
// Button 3 on GPIO7 (RTC-capable, not a strapping pin, adjacent on the header).
static ButtonState buttons[] = {
  { 5, 1, HIGH, HIGH, 0 },
  { 2, 2, HIGH, HIGH, 0 },
  { 7, 3, HIGH, HIGH, 0 },
};
static const size_t kNumButtons = sizeof(buttons) / sizeof(buttons[0]);

IRsend      irsend(kIrLedPin);
Preferences prefs;

NimBLECharacteristic* statusChar = nullptr;
static bool clientConnected = false;

// IR sends block for ~70ms and drive the RMT peripheral. Doing that inside a
// NimBLE callback runs it on the host task's limited stack, so trigger writes
// only set this flag and loop() does the actual send.
static volatile uint8_t pendingSlot = 0;

// ── status helper ───────────────────────────────────────────────────────────
void pushStatus(const String& msg) {
  Serial.print("[status] ");
  Serial.println(msg);
  if (statusChar) {
    statusChar->setValue(msg.c_str());
    if (clientConnected) statusChar->notify();
  }
}

// ── NVS layout: per slot, keys "p<N>" proto, "c<N>" code, "b<N>" bits ────────
static String keyFor(char prefix, uint8_t slot) {
  return String(prefix) + String(slot);
}

bool slotConfigured(uint8_t slot) {
  return prefs.isKey(keyFor('p', slot).c_str());
}

void saveSlot(uint8_t slot, const String& proto, uint64_t code, uint16_t bits) {
  prefs.putString(keyFor('p', slot).c_str(), proto);
  prefs.putULong64(keyFor('c', slot).c_str(), code);
  prefs.putUShort(keyFor('b', slot).c_str(), bits);
}

// ── IR ──────────────────────────────────────────────────────────────────────
bool protoSupported(const String& p) {
  return p == "NEC" || p == "SAMSUNG" || p == "SONY";
}

bool sendIr(const String& proto, uint64_t code, uint16_t bits) {
  if (proto == "NEC")      { irsend.sendNEC(code, bits);            return true; }
  if (proto == "SAMSUNG")  { irsend.sendSAMSUNG(code, bits);        return true; }
  if (proto == "SONY")     { irsend.sendSony(code, bits, 2);        return true; }
  return false;  // Sony wants >=2 repeats to be accepted by most sets
}

// ── shared send path (BLE trigger and button presses both land here) ────────
void fireSlot(uint8_t slot) {
  String   proto = prefs.getString(keyFor('p', slot).c_str());
  uint64_t code  = prefs.getULong64(keyFor('c', slot).c_str());
  uint16_t bits  = prefs.getUShort(keyFor('b', slot).c_str());

  Serial.printf("[ir] slot %u -> %s 0x%llX (%u bits)\n",
                slot, proto.c_str(), (unsigned long long)code, bits);

  if (sendIr(proto, code, bits)) {
    pushStatus(String("sent:") + slot);
  } else {
    pushStatus(String("err:unknown proto ") + proto);
  }
}

// ── buttons ─────────────────────────────────────────────────────────────────
// Fires on the press edge only, so holding a button does not repeat.
void pollButtons() {
  const uint32_t now = millis();

  for (size_t i = 0; i < kNumButtons; i++) {
    ButtonState& b = buttons[i];
    const int level = digitalRead(b.pin);

    if (level != b.lastRead) {          // still bouncing — restart the timer
      b.lastRead = level;
      b.lastChangeMs = now;
      continue;
    }
    if (now - b.lastChangeMs < kDebounceMs) continue;   // not settled yet
    if (level == b.stable) continue;                    // no edge

    b.stable = level;
    if (level != LOW) continue;         // release edge — ignore

    Serial.printf("[btn] GPIO%u pressed -> slot %u\n", b.pin, b.slot);
    pushStatus(String("pressed:") + b.slot);

    if (!slotConfigured(b.slot)) {
      Serial.printf("[btn] slot %u is empty — nothing to send\n", b.slot);
      pushStatus(String("err:empty:") + b.slot);
      continue;
    }
    fireSlot(b.slot);
  }
}

// ── config characteristic ───────────────────────────────────────────────────
class ConfigCallbacks : public NimBLECharacteristicCallbacks {
  void onWrite(NimBLECharacteristic* c, NimBLEConnInfo& connInfo) override {
    String raw = String(c->getValue().c_str());
    Serial.print("[ble] config write: ");
    Serial.println(raw);

    JsonDocument doc;
    DeserializationError err = deserializeJson(doc, raw);
    if (err) { pushStatus(String("err:bad json (") + err.c_str() + ")"); return; }

    int slot = doc["slot"] | 0;
    if (slot < kMinSlot || slot > kMaxSlot) {
      pushStatus("err:slot must be 1-5"); return;
    }

    String proto = String((const char*)(doc["proto"] | ""));
    proto.toUpperCase();
    if (!protoSupported(proto)) {
      pushStatus("err:proto must be NEC|SAMSUNG|SONY"); return;
    }

    String codeStr = String((const char*)(doc["code"] | ""));
    codeStr.trim();
    if (codeStr.isEmpty()) { pushStatus("err:missing code"); return; }
    // base 0 so both "0xE0E040BF" and bare hex/decimal parse
    char* end = nullptr;
    uint64_t code = strtoull(codeStr.c_str(), &end, 0);
    if (end == codeStr.c_str() || *end != '\0') {
      // retry as bare hex, e.g. "E0E040BF" without the 0x
      end = nullptr;
      code = strtoull(codeStr.c_str(), &end, 16);
      if (end == codeStr.c_str() || *end != '\0') {
        pushStatus("err:bad code"); return;
      }
    }

    int bits = doc["bits"] | 32;
    if (bits <= 0 || bits > 64) { pushStatus("err:bits must be 1-64"); return; }

    saveSlot(slot, proto, code, bits);
    Serial.printf("[nvs] slot %d <- %s 0x%llX (%d bits)\n",
                  slot, proto.c_str(), (unsigned long long)code, bits);
    pushStatus(String("saved:") + slot);
  }
};

// ── trigger characteristic ──────────────────────────────────────────────────
class TriggerCallbacks : public NimBLECharacteristicCallbacks {
  void onWrite(NimBLECharacteristic* c, NimBLEConnInfo& connInfo) override {
    String raw = String(c->getValue().c_str());
    Serial.print("[ble] trigger write: ");
    Serial.println(raw);

    JsonDocument doc;
    if (deserializeJson(doc, raw)) { pushStatus("err:bad json"); return; }

    int slot = doc["slot"] | 0;
    if (slot < kMinSlot || slot > kMaxSlot) {
      pushStatus("err:slot must be 1-5"); return;
    }
    if (!slotConfigured(slot)) {
      pushStatus(String("err:slot ") + slot + " empty"); return;
    }
    pendingSlot = (uint8_t)slot;  // loop() performs the send
  }
};

// ── server callbacks ────────────────────────────────────────────────────────
class ServerCallbacks : public NimBLEServerCallbacks {
  void onConnect(NimBLEServer* s, NimBLEConnInfo& connInfo) override {
    clientConnected = true;
    Serial.println("[ble] client connected");
  }
  void onDisconnect(NimBLEServer* s, NimBLEConnInfo& connInfo, int reason) override {
    clientConnected = false;
    Serial.printf("[ble] client disconnected (reason %d), advertising again\n", reason);
    NimBLEDevice::startAdvertising();
  }
};

void setup() {
  Serial.begin(115200);
  delay(2000);                       // let USB CDC enumerate before logging
  Serial.println();
  Serial.println("=== IR-Remote Phase 3 — BLE GATT + IR + buttons ===");

  irsend.begin();
  prefs.begin("irremote", false);

  for (size_t i = 0; i < kNumButtons; i++) {
    pinMode(buttons[i].pin, INPUT_PULLUP);
    Serial.printf("[btn] GPIO%u -> slot %u (INPUT_PULLUP, pressed = LOW)\n",
                  buttons[i].pin, buttons[i].slot);
  }

  // Seed slot 1 with the Samsung power code proven in Phase 1, first boot only.
  if (!slotConfigured(1)) {
    saveSlot(1, "SAMSUNG", 0xE0E040BFULL, 32);
    Serial.println("[nvs] seeded slot 1 = SAMSUNG 0xE0E040BF (32 bits)");
  }

  NimBLEDevice::init(kDevName);
  NimBLEServer* server = NimBLEDevice::createServer();
  server->setCallbacks(new ServerCallbacks());

  NimBLEService* service = server->createService(SERVICE_UUID);

  NimBLECharacteristic* configChar =
      service->createCharacteristic(CONFIG_UUID, NIMBLE_PROPERTY::WRITE);
  configChar->setCallbacks(new ConfigCallbacks());

  NimBLECharacteristic* triggerChar =
      service->createCharacteristic(TRIGGER_UUID, NIMBLE_PROPERTY::WRITE);
  triggerChar->setCallbacks(new TriggerCallbacks());

  statusChar = service->createCharacteristic(
      STATUS_UUID, NIMBLE_PROPERTY::READ | NIMBLE_PROPERTY::NOTIFY);
  statusChar->setValue("ready");

  service->start();

  // The advertising payload is 31 bytes and a 128-bit service UUID eats 18 of
  // them (+3 flags), leaving no room for an 11-byte name field — the name would
  // be silently dropped or truncated, so a name-based scan filter never matches.
  // Keep the UUID in the advertisement and put the name in the scan response,
  // which gets its own 31 bytes.
  NimBLEAdvertising* adv = NimBLEDevice::getAdvertising();

  NimBLEAdvertisementData advData;
  advData.setFlags(BLE_HS_ADV_F_DISC_GEN | BLE_HS_ADV_F_BREDR_UNSUP);
  advData.addServiceUUID(SERVICE_UUID);
  adv->setAdvertisementData(advData);

  NimBLEAdvertisementData scanData;
  scanData.setName(kDevName);
  adv->setScanResponseData(scanData);
  adv->enableScanResponse(true);

  NimBLEDevice::startAdvertising();

  Serial.printf("[ble] advertising as \"%s\"\n", kDevName);
  Serial.printf("[ble] service %s\n", SERVICE_UUID);
  Serial.println("[ble] ready — waiting for a client");

  // Show what's already stored, so the serial log alone explains the state.
  for (uint8_t s = kMinSlot; s <= kMaxSlot; s++) {
    if (!slotConfigured(s)) continue;
    Serial.printf("[nvs] slot %d = %s 0x%llX (%u bits)\n", s,
                  prefs.getString(keyFor('p', s).c_str()).c_str(),
                  (unsigned long long)prefs.getULong64(keyFor('c', s).c_str()),
                  prefs.getUShort(keyFor('b', s).c_str()));
  }
}

void loop() {
  uint8_t slot = pendingSlot;
  if (slot) {
    pendingSlot = 0;
    fireSlot(slot);
  }

  pollButtons();
  delay(5);   // 5ms poll is well inside the 30ms debounce window
}

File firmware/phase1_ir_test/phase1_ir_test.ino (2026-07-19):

/*
 * Phase 1 — IR transmit proof (ESP32-S3)
 *
 * Sends one IR power code every 3 seconds. Point it at the target device.
 * Pass gate: the device powers off/on. Sanity check: watch the IR LED
 * through your phone's SELFIE camera — it should flash purple.
 *
 * Wiring (salvaged NPN transistor, e.g. S8050/2N2222):
 *   GPIO4 ──1kΩ──> transistor BASE
 *   transistor EMITTER ──> GND
 *   3V3 ──~100Ω──> IR LED anode(+) ──> IR LED cathode(-) ──> transistor COLLECTOR
 *
 * Library: IRremoteESP8266 (>= 2.9.0 for S3) via Arduino Library Manager.
 * Board: "ESP32S3 Dev Module", ESP32 Arduino core 3.x.
 */

#include <IRremoteESP8266.h>
#include <IRsend.h>

const uint16_t kIrLedPin = 4;
IRsend irsend(kIrLedPin);

// ── Target: Samsung TV power toggle (works across nearly all Samsung TVs) ──
const uint64_t kCode = 0xE0E040BF;
// Other brands for later:
// LG TV power (NEC):  irsend.sendNEC(0x20DF10EF, 32);
// Sony TV power:      irsend.sendSony(0xA90, 12, 2);  // Sony wants 2+ repeats
// ──────────────────────────────────────────────────────────────────────────

void setup() {
  Serial.begin(115200);
  irsend.begin();
  Serial.println("Phase 1 IR test: sending Samsung power 0xE0E040BF every 3s");
}

void loop() {
  irsend.sendSAMSUNG(kCode, 32);
  Serial.println("sent");
  delay(3000);
}

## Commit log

2026-07-19 Initial commit: plan, Phase 1 IR firmware, briefs, status
    Phase 1 complete — ESP32-S3 sends Samsung power code over IR on GPIO4,
    verified end-to-end by toggling the target TV.
2026-07-19 Phase 2: BLE GATT firmware + Web Bluetooth app
    Adds firmware/remote_ble (NimBLE + IRremoteESP8266): one GATT service with
    config/trigger/status characteristics, five IR slots persisted to NVS via
    Preferences. IR sends are deferred from the BLE callback to loop() so the
    ~70ms RMT send does not run on the NimBLE host task's stack.
    Adds app/index.html: self-contained Web Bluetooth client, no build step.
    Advertising note: a 128-bit service UUID plus the device name overflows the
    31-byte advertisement, which silently dropped the name and broke name-based
    scan filters. The name now goes in the scan response and the app filters on
    the service UUID.
    Pass gate met: TV toggles from a button in the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
    [remote_ble.ino]
2026-07-19 Phase 3: NPN driver stage + physical buttons
    Hardware: 2N2222 off the 5V rail (33R, two IR LEDs in series, 1k base)
    replaces direct GPIO drive. ~64mA vs ~13mA, taking range from ~5ft to 20-30ft.
    Firmware: GPIO5 -> slot 1, GPIO2 -> slot 2, INPUT_PULLUP, 30ms debounce,
    fires on the press edge only so holding does not repeat. BLE trigger and
    button presses share one fireSlot() path. Presses notify pressed:N, and an
    unprogrammed slot reports err:empty:N.
    Button 2 moved from the planned GPIO6 to GPIO2 — GPIO6 is not broken out on
    this devkit. GPIO2 is a strapping pin on the classic ESP32 but not on the S3
    (0/3/45/46 there), and it is RTC-capable so Phase 4 EXT1 wake still works.
    App: pressed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
    [remote_ble.ino]
2026-07-21 IR code library: Flipper-IRDB import, converter, browsable app UI
    Adds a local IR code database derived from Flipper-IRDB so slots can be
    filled by picking brand/model instead of pasting hex by hand.
    - data/db/: ~400 per-brand JSON files across TVs, soundbars, projectors,
    AV receivers, cable boxes, blu-ray, DVD, monitors + index.json
    - tools/flipper_ir_convert.py: .ir -> JSON converter
    - app/index.html: browse/search the library and load a code into a slot
    - docs/: code-library design, Phase 5 and PCB briefs
2026-07-21 hardware: PCB design doc, fab notes, and MCP connectivity repair script
    Groundwork for the custom BLE IR remote board (KiCad 10, 2-layer, 30x58mm).
    fix-nets.py is not optional. The kicad-mcp board writer serialises pad nets
    as (net "GND") with no net index and omits the top-level net table entirely.
    KiCad opens such a file without complaint but every pad is netless, so DRC
    reports a clean board while being unable to detect a single short. Every MCP
    save re-breaks it, hence the mandatory order:
    <mcp edit> -> save_project -> fix-nets.py -> kicad-cli drc
    Documented in hardware/README.md and STATUS.md so it doesn't cost an
    afternoon in three weeks.
    DESIGN-pcb.md records the decisions and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
2026-07-21 hardware: retract the "MCP destroys connectivity" finding, drop fix-nets.py
    The previous commit claimed the kicad-mcp board writer corrupted the net table
    and shipped fix-nets.py to repair it. That was wrong, and both the claim and
    the script are withdrawn.
    KiCad 10 (board format 20260206) references nets by name -- (net "GND") --
    having dropped the numeric index and the top-level (net N "name") table used by
    KiCad <= 9. kicad-cli --save-board, KiCad's own serialiser, writes exactly that
    form and DRC resolves it correctly (Pad 5 [BTN1], Track [BTN1]). The MCP output
    was correct; the board was never broken.
    The false positive came from `grep '(net [0-9]'` returning zero -- which is a
    fact a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
2026-07-21 hardware: 30x58mm board, placed, poured and part-routed; DRC clean
    Board grown from 30x50 to 30x58mm (approved). The ESP32-S3-WROOM-1 footprint
    declares a large antenna clearance area -- x < 7.75mm for the full board
    height -- and at 30x50 that put R13, SW1, SW4 and SW6 inside it with 15 further
    courtyard overlaps. The tactile footprints carry their own 8mm keepouts too, so
    three buttons across do not fit in the width that remains; buttons are now in
    three rows, with the full-width row above the keepout boundary.
    State:
    - DRC 0 violations at JLCPCB rules (0.127mm track, 0.2mm clearance,
    0.3mm min drill), zones filled
    - antenna keepout verified clear by direct copper audit, independe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
    [ir-remote.kicad_pcb, ir-remote.kicad_sch]
2026-07-21 hardware: GND cannot be carried by the pour on this board -- diagnosis + state
    DRC still 0 violations at JLCPCB rules, antenna keepout verified clear by direct
    copper audit. 295 tracks, 131 vias, both GND pours restored. 26 unconnected
    items remain (GND 32 endpoints, +3V3 8, VBUS 6, and three signal nets).
    Key finding, which cost several iterations and would otherwise have shipped as a
    dead board:
    - Pours on both layers plus 90 stitching vias still left ~32 GND endpoints
    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
    [ir-remote.kicad_pcb]
2026-07-26 perf-board: range restored + button 1 pin fix; chapter closed
    Bench session 2026-07-26 closed out the perf-board rebuild:
    - Transistor E/C-reversed fault (root cause from 2026-07-21) is fixed: 2N2222
    reinstalled correctly. Steady-drive check shows both IR LEDs bright at full
    ~100mA and a live range test toggles the TV across the room. Pass gate met.
    - Button 1 was mapped to GPIO6 in the uncommitted firmware, but pin 6 was never
    wired -- boot printed clean, no press ever registered. Reverted to GPIO5
    (its original Phase 3 pin). All three buttons (GPIO5/GPIO2/GPIO7) verified on
    serial; buttons 3 added (GPIO7 -> slot 3).
    - Power-off safety sweep after a transient prong short came bac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
    [remote_ble.ino]
2026-07-26 phase5 Sitting A: search-first library, generic codes, search index
    Steps 1-4 of the Phase 5 brief (spec: docs/DESIGN-code-library.md).
    Converter (tools/flipper_ir_convert.py), re-scraped from a fresh Flipper-IRDB:
    - Search index (data/db/search.json, 61KB, 317 brand records) — brand +
    category + canonical functions + model strings, so the app is search-first;
    shards still lazy-load on selection.
    - Generic/blanket codes: model-spread measured before dedupe; a canonical code
    shared across >=3 models in a brand is flagged generic (+nmodels). Samsung TV
    0xE0E040BF = power_toggle across 36 models.
    - Sweep lists now order power_on before toggle before power_off.
    - New sanity gates for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
2026-07-31 docs: point DESIGN-pcb.md at docs/DEVLOG.md after the rename
2026-07-31 docs: restore markdown formatting in README
    The text was committed with the markdown stripped, so headings, code fences, the pin-map table and inline code all rendered as one run of prose. Same content, correct syntax, plus links for the Flipper sources and Ko-fi.
2026-07-31 readme: reframe status as finished-with-edges, add a "What's next"
    The forward-looking text was written in this project's internal vocabulary —
    "Phase 5 Sitting B", "Phase 4", "pass gate" — which means nothing to someone
    arriving cold and reads like a stalled backlog rather than a working project.
    None of that jargon survives in the README; it stays in docs/DEVLOG.md, where a
    development log is supposed to sound like one.
    "Status — honest version" becomes "Where it stands", leading with the fact that
    the thing works and is finished, then listing the honest edges as
    characteristics rather than apologies. The dead dev board is framed as the
    story it is — a boost converter that drifted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
